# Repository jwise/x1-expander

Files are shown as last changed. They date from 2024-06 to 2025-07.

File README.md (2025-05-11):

# X1Plus Expander

This repository contains hardware development files for the X1Plus Expander,
[available-ish for purchase at Crowd
Supply](https://www.crowdsupply.com/accelerated-tech/x1plus-expander). 
Printer-side software to interface with these boards lives in the [X1Plus
repository](https://github.com/x1plus/x1plus).

If you have just purchased an Expander, you probably want to [read the
getting started guide](doc/getting-started.md)!

Each part has its own directory in this repository.  Part numbers always
begin with "X1P", are followed by three digits to identify the part, and
have a three-character revision number: a letter to identify
form/fit/function-incompatible revisions, and two digits to identify
FFF-compatible revisions.  Put together, a part and revision number looks
like "X1P-002-C02", to identify the an X1Plus Expansion Board mainboard, the
third FFF-incompatible revision, and the second FFF-compatible revision of
the X1P-002-C family.

This repository contains the following parts.  (Descriptions below may not
be representative of marketing names.)

 * [X1P-001](x1p-001/): wiring harness to connect X1P-002 to the printer
 * [X1P-002](x1p-002/): X1Plus Expander mainboard
 * [X1P-003](x1p-003/): manufacturing test harness for X1P-002
 * [X1P-004](x1p-004/): LED strip 3.3V->5V level shifter plugin
 * [X1P-005](x1p-005/): Andon board plugin
 * [X1P-006](x1p-006/): 2.5mm camera shutter release plugin
 * X1P-100 is a part number reserved for a bundle assembly of X1P-001,
   X1P-002, and X1P-800.
 * [X1P-800](x1p-800/): plastics for X1P-002

Ideally, each known version of each of these parts has its own git tag and
GitHub release with manufacturing data.  (Ideally.)

Also in this repository:

 * [utils/](utils/): software useful in manufacturing or bringup of X1P-*
   hardware
 * [doc/](doc/): documentation associated with X1P-* hardware
 * [fw/](fw/): firmware for the RP2040 on X1P-002-C series boards

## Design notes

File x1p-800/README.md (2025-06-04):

These plastics go with X1P-002-Bxx and X1P-002-Cxx boards.  See [assembly
documentation](../doc/assembly.md) for suggested assembly instructions.

See [OnShape
source](https://cad.onshape.com/documents/978d60c454bcccf39dac29ae/w/00e32d7fbc9730699d7762b9/e/21185136b3366b7afc3fb981)
to edit.

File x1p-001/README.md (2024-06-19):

To build: `wireviz harness.yaml -o X1P-001`

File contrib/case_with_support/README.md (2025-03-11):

This directory contains an alternative case designed by @liftbag (originally
shown
[here](https://github.com/X1Plus/X1Plus/discussions/445#discussioncomment-12460478)). 

This case offers nicer ergonomics and a more secure way to mount it, in
exchange for the need to print it with supports.  It hasn't been tested with
a real PCBA yet, but if you're willing to print with supports, I encourage
you to give it a try!

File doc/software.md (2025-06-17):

# Getting started with X1Plus Expander

This assumes that you have already [assembled the hardware](assembly.md).

## Installing a firmware

You will need to install an X1Plus firmware build that supports X1Plus
Expander.  Versions 3.0 and higher support the X1Plus Expander; if you're
currently running version 2.0 or higher, you can [use the built-in
over-the-air update
mechanism](https://github.com/X1Plus/X1Plus/wiki/User-Manual#over-the-air-updates-version-20-and-up). 
From earlier versions, please follow the "manual upgrade" steps [in the user
manual](https://github.com/X1Plus/X1Plus/wiki/User-Manual#manual-upgrades).

If you are running a firmware version that supports X1Plus Expander, you
should see "Expansion" appear in the "Hardware" tab, and if X1Plus Expander
is connected correctly and functioning properly, you should also see a
serial number appear underneath it.  You should also see "Wired Network"
appear in the "Network" tab if X1Plus Expander is connected and functioning.

## Connecting hardware to X1Plus Expander

X1Plus Expander port (the rectangular connectors on the top) are identified
by letters.  "B01" revisions of X1Plus Expander have only two functioning
ports -- the port on the left of X1Plus Expander (next to the I2C connector)
is "port B", and the connector two over from that is "port A".  (The port on
the right, and the port between port A and port B, are not usable in X1Plus
Expander B01; X1Plus Expander B01 hardware labels the usable ports in
silkscreen as "AD" and "BD".  All four ports will be usable in X1Plus
Expander revision C.) The leftmost port (port B, on revision B01) is always
shared with the STEMMA I2C connector.

It is better to power the printer off before connecting or disconnecting
add-on modules to the X1Plus Expander ports, but I can't stop you if you
really want to try it, and chances are good that you will probably get away
with it most of the time.

Add-on modules are not keyed right now.  Make sure that they are centered in
the port, and make sure that they face forward (i.e., that the arrow on the
add-on module matches up with the arrow on the port).

You can also connect other hardware to X1Plus Expander, using any standard
0.1" Dupont-style connector.  Doing so is outside of the scope of this
document, but if you get a hankering to do it, let me know what you are
trying to do and I will try to think up how you would do it, and document
it.

## Configuring X1Plus Expander

Currently, X1Plus Expander is primarily configured through the command line,
using the `x1plus settings` mechanism; a GUI to configure the ports is in
progress.  You can list all of X1Plus's settings with the `x1plus settings
get` command; conversely, you can also change settings with `x1plus settings
set`.  (You can run `x1plus settings set --help` to see exactly how it is
used.)

The settings keys for X1Plus Expander ports are `expansion.port_a` and
`expansion.port_b`, and should contain JSON objects that describe what is
connected to a port.  The exact format for these JSON objects is slightly in
flux, so for now, I'll provide recipes for setting up each supplied add-on
module:

### X1P-004 LED-strip level shifter module

Configure a port to drive an LED strip with:

```
# x1plus settings set expansion.port_x --json '{"ledstrip": {"leds": 10}}'
```

where "port_x" is correct for the port that you have plugged the X1P-004
into, and "10" has been changed to the correct number of LEDs in your LED
strip that you'd like to light up.  If you'd like to control which
animations are visible on your LED strip:

```
# x1plus settings set expansion.port_x --json '{"ledstrip": {"leds": 10, "animations": [{"running": {"brightness": 0.05}}, {"finish": {"brightness": 0.1}}]}}'
```

Available animations are `rainbow`, `paused`, `failed`, `running`, and
`finish`.  All animations take an optional `brightness` parameter (scaled
from 0 to 1); `failed` and `finish` also take an optional `timeout`
parameter (in seconds) to describe how long they should remain, before
returning to either a rainbow or a blank animation.

If you find it easier, you can also configure a port using a JSON or YAML
file, rather than having to input an entire JSON string in a command line
parameter.  For instance, you can do:

```
# cat > ledstrip.yaml <<EOF
ledstrip:
  animations:
  - running:
      brightness: 0.05
  - finish:
      brightness: 0.1
  leds: 10
EOF
# x1plus settings set expansion.port_x --file ledstrip.yaml --yaml
```

You may find this more convenient to experiment with.

TODO: document where to connect what for LED strips, and how to use an external power supply, if it is not obvious

### X1P-005 Andon module

An Andon module is just an LED strip module with 25 fixed LEDs on it, a
buzzer, and two buttons that serve as inputs.  This introduces the `gpio`
parameter to the `ledstrip` type of module.  I recommend a configuration for
X1P-005 that looks about as follows:

```
# x1plus settings set expansion.port_x --json '{"ledstrip": {"leds": 25, "gpios": [{"pin": 3, "function": "buzzer", "default": 0}, {"pin": 5, "default": 1}, {"pin": 6, "function": "button", "inverted": true}, {"pin": 7, "function": "button", "inverted": true}]}}'
```

You may also consider a YAML equivalent, if you wish to play with the
animations.  For instance, consider:

```
# cat > andon.yaml <<EOF
ledstrip:
  animations:
  - running:
      brightness: 0.05
  - rainbow:
      brightness: 0.1
  gpios:
  - pin: 3
    function: buzzer
    default: 0
  - pin: 5
    default: 1
  - pin: 6
    function: button
    inverted: true
  - pin: 7
    function: button
    inverted: true
  leds: 25
```

The Andon module will, by default, light up like any other LED strip.  To
use the buzzer or buttons, see the "Using X1Plus Actions" section, below.

### X1P-006 Shutter release module

A shutter release module is a GPIO module that has two outputs. 
Conveniently, the `ledstrip` driver can be used to drive GPIOs (the shutter
release module does not have anything connected to the LED output pin).  You
can configure a shutter release module as follows:

```
# x1plus settings set expansion.port_x --json '{"ledstrip": {"leds": 0, "gpios": [ { "pin": 3, "function": "shutter", "default": 0 }, { "pin": 5, "function": "shutter", "default": 0 } ] } }'
```

### Using I2C sensors

TODO: document `i2c` driver

## Using X1Plus Actions

X1Plus Actions is a new mechanism to trigger behavior from inside X1Plus. 
Actions are a commonized way to trigger tasks from the command line, from
G-code, or in response to various system events (including button presses). 
Actions are either a JSON dictionary specifying an Action, or a list of
Actions.  For instance, the following is a valid Action:

```json
{
  "gpio": {
    "action": "pulse",
    "duration": 0.5,
    "gpio": {
      "function": "buzzer"
    }
  }
}
```

This Action calls the "gpio" action type, and provides it with three
parameters -- a subaction ("pulse", which turns a GPIO on for `duration`
time, and then turns it back off), a duration, and a GPIO specification.  In
this case, the GPIO specification causes the `pulse` to match all GPIOs on
the system that have a `function` of `buzzer`.

The following is also a valid Action:

```json
{ "delay": 0.5 }
```

This Action simply waits for 0.5 seconds before proceeding.  If you executed
this Action on its own, you would see nothing, but if you created a list of
Actions with this as a part of it, you would see a delay happen in between
beeps:

```json
[
  {"gpio": {"action": "pulse", "duration": 0.5, "gpio": {"function": "buzzer"}}},
  {"delay": 0.5},
  {"gpio": {"action": "pulse", "duration": 0.5, "gpio": {"function": "buzzer"}}}
]
```

Another useful type of action is to submit G-code to the MC.  For instance,
you might consider:

```json
{"gcode": "G91\nG0 Z-7.5"}
```

which puts the printer into relative mode, and then jogs the Z axis.

### Testing Actions from the command line

You can use the `x1plus action` command to submit an Action from the command
line.  Like `settings`, it allows you to use JSON on the command line, JSON
from a file, or YAML from a file.  For instance, to make a pleasing
bee-beep! sound from any buzzers that you have connected, consider:

```
# x1plus action --json '[{"gpio": {"action": "pulse", "duration": 0.08, "gpio": {"function": "buzzer"}}}, {"delay": 0.08}, {"gpio": {"action": "pulse", "duration": 0.05, "gpio": {"function": "buzzer"}}}]'
```

You may find it more friendly to edit your actions in JSON on disk.  For
instance, you might prefer:

```
# cat > beep.json <<EOF
[
    {
        "gpio": {
            "action": "pulse",
            "duration": 0.08,
            "gpio": {
                "function": "buzzer"
            }
        }
    },
    {
        "delay": 0.08
    },
    {
        "gpio": {
            "action": "pulse",
            "duration": 0.05,
            "gpio": {
                "function": "buzzer"
            }
        }
    }
]
EOF
# x1plus action --json --file beep.json
```

Or you may even prefer to edit your actions in YAML, since after all, JSON
is a rather unpleasant language to write by hand.  For this, you might
prefer:

```
# cat > beep.yaml <<EOF
- gpio:
    action: pulse
    duration: 0.08
    gpio: 
      function: buzzer
- delay: 0.08
- gpio:
    action: pulse
    duration: 0.05
    gpio: 
      function: buzzer
EOF
# x1plus action --yaml --file beep.yaml
```

If you have an X1P-007 shutter release connected, you might otherwise prefer
to trigger a shutter to test it.  Connect your camera, and try:

```
# x1plus action --json '{"gpio": {"action": "pulse", "duration": 0.15, "gpio": {"function": "shutter"}}}'
```

You can match on other properties, as well.  For instance, if you'd like to
trigger only one of the two connected cameras, and you care about which port
it's on:

```
# x1plus action --json '{"gpio": {"action": "pulse", "duration": 0.15, "gpio": {"function": "shutter", "pin": 3, "port": "b"}}}'
```

This matches on only things that have a function of "shutter", *and* are on
pin 3, *and* are plugged into port B.

### Embedding Actions in G-code

*This section describes in detail how G-code embedded Actions work, but if
you would just like some recipes that you can paste into the G-code window
in your slicer, see below.*

You can run X1Plus Actions from inside G-code.  The general concept is that
you define an action number using a specially-formatted `;x1plus define`
comment, and then use the G-code command `M976 S99 Pn` to trigger it.  For
instance, you can trigger the buzzer with a G-code command sequence as
follows:

```
G0 X... Y...
;x1plus define 5 {"gpio": {"action": "pulse", "duration": 0.2, "gpio": {"function": "buzzer"}}}
M976 S99 P5
G0 X... Y...
```

(Note that an `;x1plus define` must always come before its respective `M976
S99`, and you should not redefine an action number to a new value later in a
print -- however, it is safe to redefine an action to the same value as it had
previously, however.)

#### Using compiled Actions in G-code

Unfortunately, most slicers will not accept commands with `{curly braces}`
-- they seem to interpret these as variable substitution.  X1Plus supports
an alternate "compiled" syntax, which does not include curly braces; you can
use the `x1plus convert` command to convert JSON or YAML into the "compiled"
form.  For instance, you can convert the above action as:

```
# x1plus convert '{"gpio": {"action": "pulse", "duration": 0.2, "gpio": {"function": "buzzer"}}}'
eNqrVkovyMxXslKoVkpMLsnMzwMylQpKc4pTlXQUlFJKixKhggZ6RkABuOK00jy48qTSqqrUIqXa2loAyekZIg==
```

Or, equivalently:

```
# cat > beep.yaml <<EOF
gpio:
  action: pulse
  duration: 0.2
  gpio:
    function: buzzer
EOF
# x1plus convert --file beep.yaml
eNqrVkovyMxXslKoVkpMLsnMzwMylQpKc4pTlXQUlFJKixKhggZ6RkABuOK00jy48qTSqqrUIqXa2loAyekZIg==
```

You can use this "compiled" string the same way as you would a JSON string. 
For instance, to beep on each layer change, you could insert the following
into your layer change G-code in your slicer:

```
;x1plus define 1 eNqrVkovyMxXslKoVkpMLsnMzwMylQpKc4pTlXQUlFJKixKhggZ6RkABuOK00jy48qTSqqrUIqXa2loAyekZIg==
M976 S99 P1
```

You can also use `x1plus convert` to produce readable JSON or YAML from
compiled Actions:

```
# x1plus convert --to=json eNqrVkovyMxXslKoVkpMLsnMzwMylQpKc4pTlXQUlFJKixKhggZ6RkABuOK00jy48qTSqqrUIqXa2loAyekZIg==
{
    "gpio": {
        "action": "pulse",
        "duration": 0.2,
        "gpio": {
            "function": "buzzer"
        }
    }
}
```

#### Pausing G-code until an Action completes

By default, `M976 S99`-triggered Actions will run in parallel with G-code --
i.e., movement commands will continue to run while the Action runs.  For
certain actions -- like time lapses, or waiting for external GPIOs, you may
wish to have G-code wait until an Action completes.  You can do this using
the `M400 W1` and `M400 W0` G-code commands.  `M400 W1` will cause G-code to
stop executing until an Action sends a `M400 G0` G-code.  For example,
consider the following G-code sequence:

```
G0 X100 Y175  ; move the toolhead
G0 X100 Y100
M400          ; wait for all toolhead motion to complete
; Define an action that pulses the shutter, waits, and then resumes G-code execution.
;x1plus define 1 [{"gpio": {"action": "pulse", "duration": 0.5, "gpio": { "function": "shutter" }}}, {"delay": 1.0}, {"gcode": "M400 W0"}]
M976 S99 P1   ; trigger the action
M400 W1       ; pause until the M400 W0 is sent
G0 X175 Y100  ; move the toolhead
G0 X175 Y175
```

This sequence, as described, causes the printer to stop moving until the
Action finishes and the camera has taken its photo (as one might hope for a
potentially long exposure required for good depth of field!).

#### Recipe: triggering a shutter on layer change

The above G-code is appropriate for triggering a shutter, but is not
suitable for embedding in a slicer configuration -- the Action is not
encoded in compiled format.  To use an Action to trigger a shutter, modify
the Machine G-code in your slicer, and add the following to the Layer change
G-code:

```
M400
; pulse shutter for 0.5 seconds, and then wait 1.0 seconds before proceeding
;x1plus define 100 eNqLrlZKL8jMV7JSqFZKTC7JzM8DMpUKSnOKU5V0FJRSSosSoYIGeqZAAbjitNI8uPLijNKSktQipdraWh2gVEpqTmIlUNxQzwDMT0/OT0kFqfM1MTBQCDdQqo0FAMvxJHo=
M976 S99 P100
M400 W1
```

Place these commands immediately underneath the `M971 S11 C10 O0` command. 
(This command will appear twice: one for "without wipe tower", and one for
"with wipe tower".  Insert the commands underneath both.

To start off with, I suggest the following (he says, as a checklist for
himself...):

* Make sure your camera has auto white balance turned off; that your camera
  is set for a fixed ISO, shutter speed, and aperture; and that your camera
  will not attempt to autofocus.
* Home the bed before printing, and then move the toolhead out of the way,
  move the bed up, and focus on or slightly beyond the bed.
* If using a macro / zoom lens, you probably want to stop the aperture down
  more than you think to achieve a usably wide depth of field.
* You probably do not want to shoot 800 RAW photos, so if you normally shoot
  RAW, remember to set the camera to JPEG only...
* Unsurprisingly, smaller layer heights result in "smoother" time lapses.
* The object will grow taller than you think.  If you are zoomed way in,
  consider putting the build area for your part in the very top of the
  frame.
* Don't be afraid to take long exposures!
* If it's an option on your camera, remember to connect it to external
  power (or use a battery emulator, if you're on a camera that has the
  shutter release occupy the same plug as a power adapter).
* Make sure your camera has auto-sleep turned off, if applicable.
* Give your test image one last pixel-peep to make sure you aren't about to
  take a 12 hour time lapse of crap...

#### Recipe: sounding the buzzer

You may also wish to sound the buzzer, either at the end of a print, or upon
a certain layer being reached.  You can paste the following G-code into a
slicer to sound the buzzer for half a second:

```
; sound buzzer for 0.5 seconds
;x1plus define 101 eNqrVkovyMxXslKoVkpMLsnMzwMylQpKc4pTlXQUlFJKixKhggZ6pkABuOK00jy48qTSqqrUIqXa2loAylIZJQ==
M976 S99 P101
```

### Triggering Actions from buttons

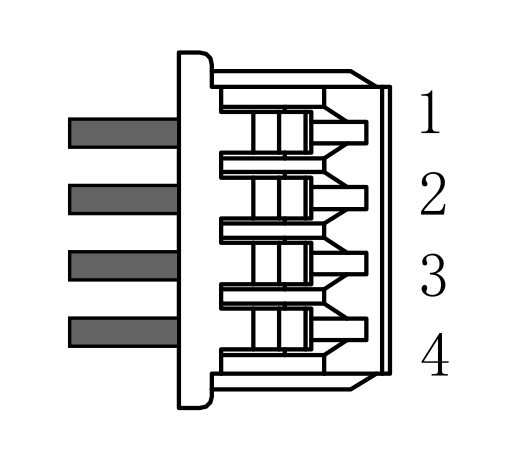
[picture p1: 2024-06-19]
x1p-001/dll_mh1_25_4y.png

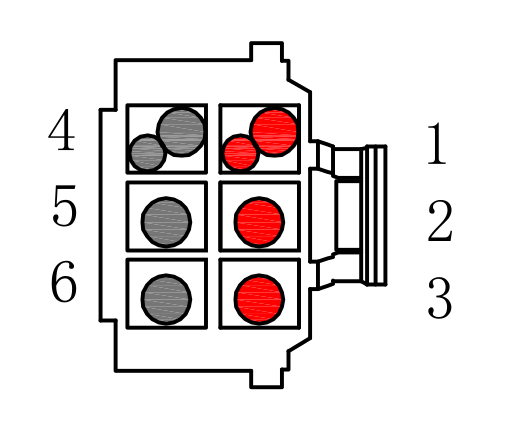
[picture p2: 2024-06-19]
x1p-001/hc_phb_2_3_y.png

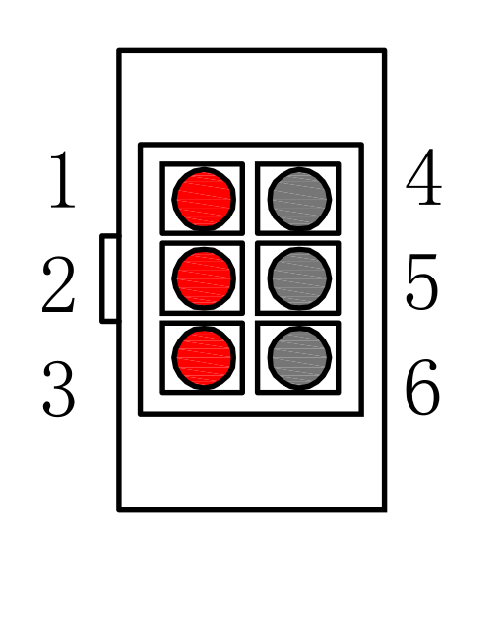
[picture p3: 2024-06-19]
x1p-001/hc_phb_2_3_ey.png

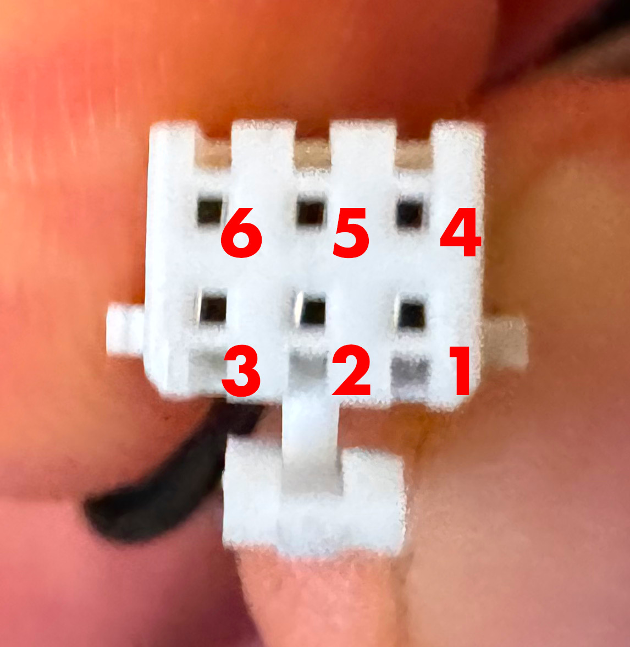
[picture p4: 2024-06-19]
x1p-001/hc_phb_2_3_y.jpg

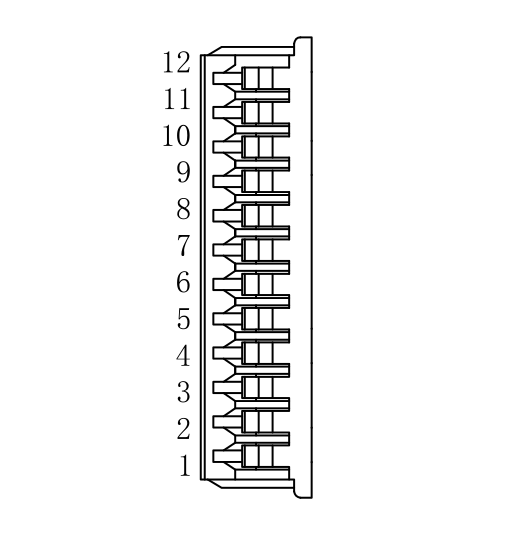
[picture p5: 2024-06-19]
x1p-001/dll_mh1_25_12y.png

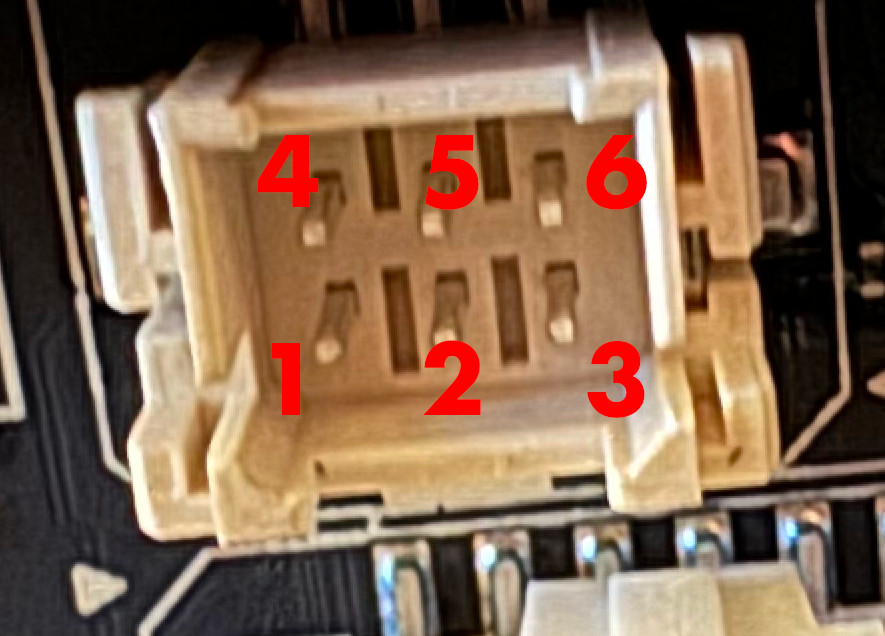
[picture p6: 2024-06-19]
x1p-001/hc_phb_2_3_ey.jpg

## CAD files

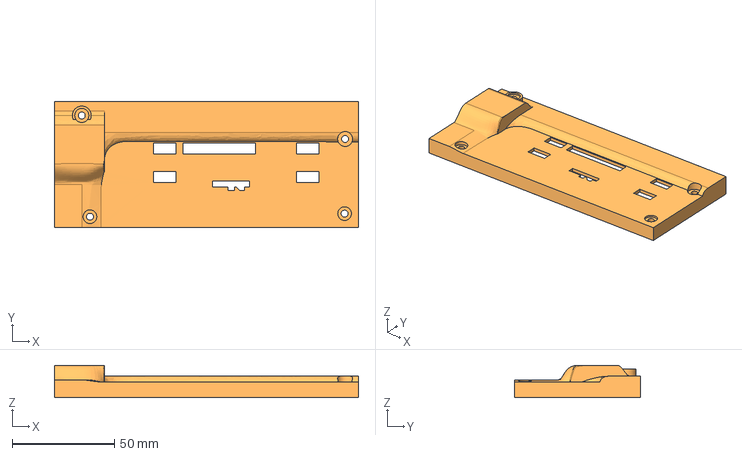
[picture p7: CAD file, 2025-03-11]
contrib/case_with_support/upper_shell.step
148.6 x 61.7 x 15.9 mm

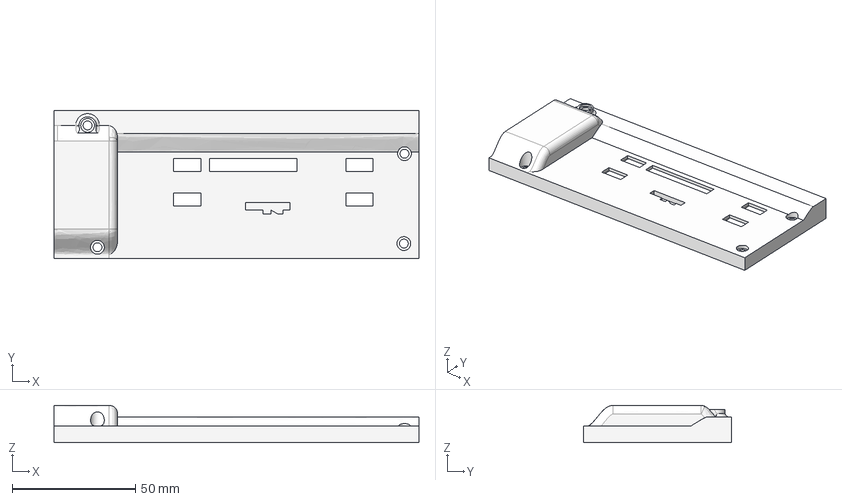
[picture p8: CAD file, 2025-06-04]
x1p-800/FDM/X1P-800 Upper shell.step
148.3 x 60.3 x 15.1 mm

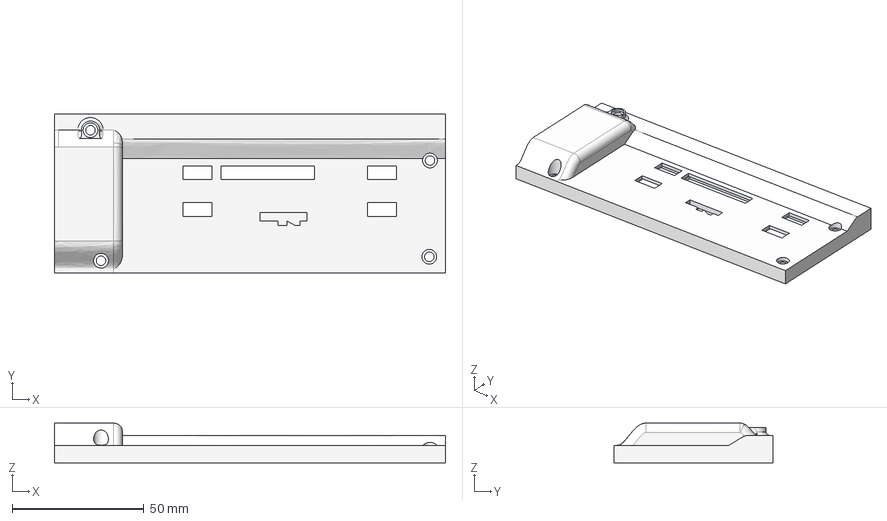
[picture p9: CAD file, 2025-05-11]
x1p-800/SLS/X1P-800-A02-B.step
148.3 x 60.3 x 15.1 mm

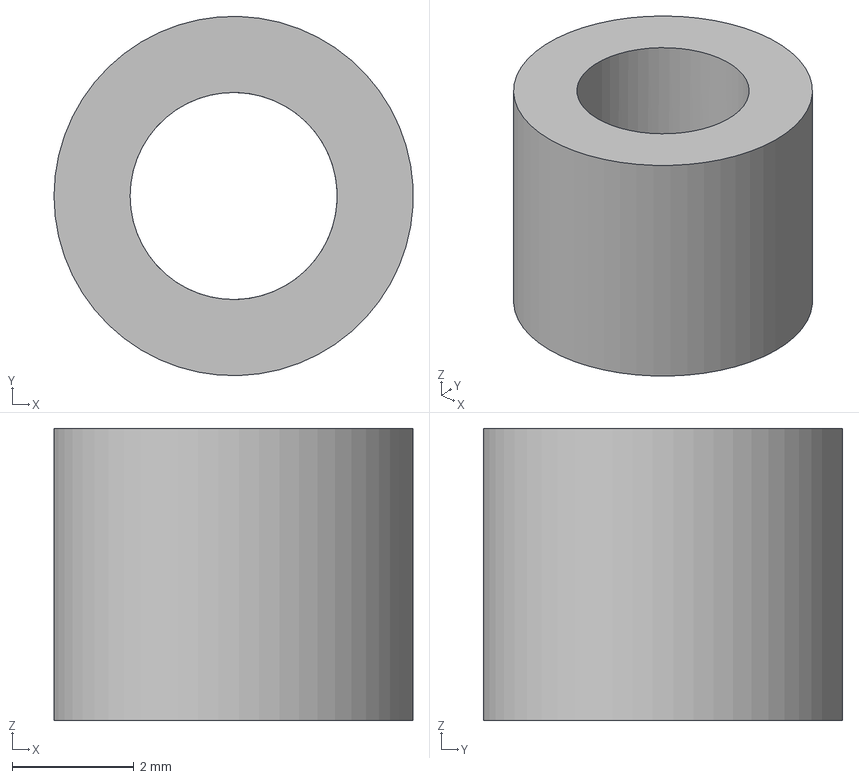
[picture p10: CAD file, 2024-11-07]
x1p-800/X1P-800 Standoff LL.step
5.90 x 5.90 x 4.80 mm

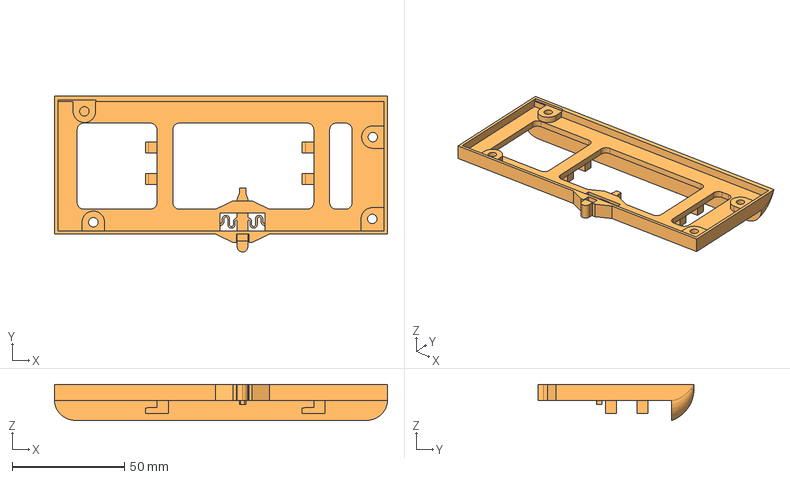
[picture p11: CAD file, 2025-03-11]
contrib/case_with_support/lower_shell.step
148.6 x 69.7 x 16.1 mm

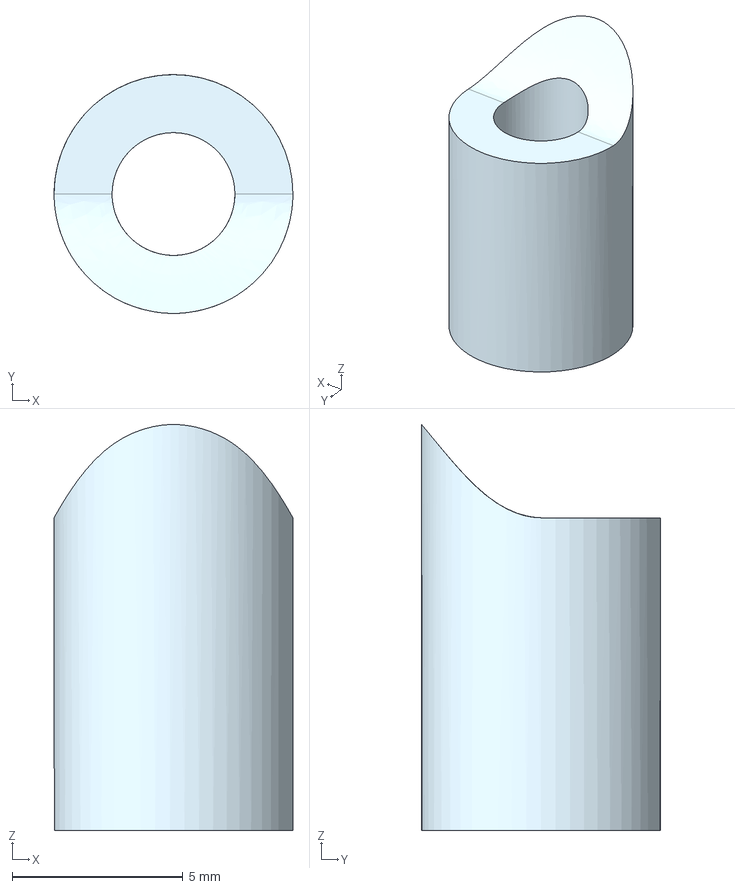
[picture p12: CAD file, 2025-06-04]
x1p-800/FDM/X1P-800 Tall standoff.step
7.00 x 7.00 x 11.9 mm

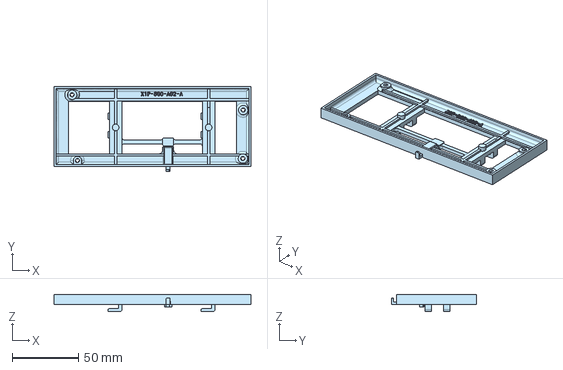
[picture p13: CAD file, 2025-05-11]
x1p-800/SLS/X1P-800-A02-A.step
148.3 x 63.8 x 13.0 mm

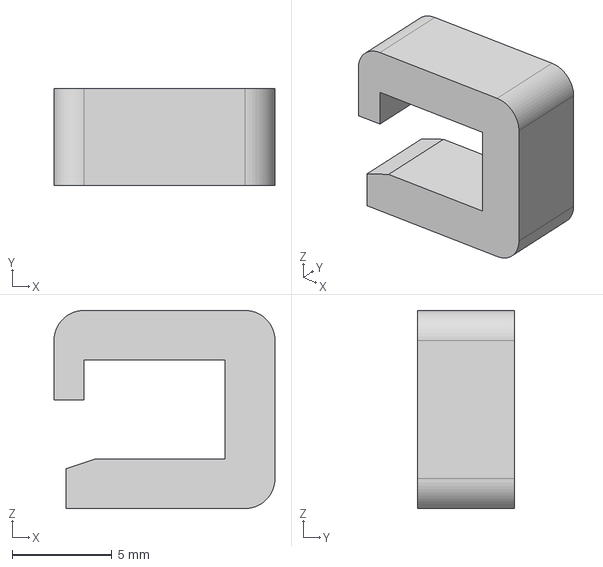
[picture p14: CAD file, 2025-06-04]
x1p-800/FDM/X1P-800 Clip.step
11.1 x 4.85 x 9.95 mm

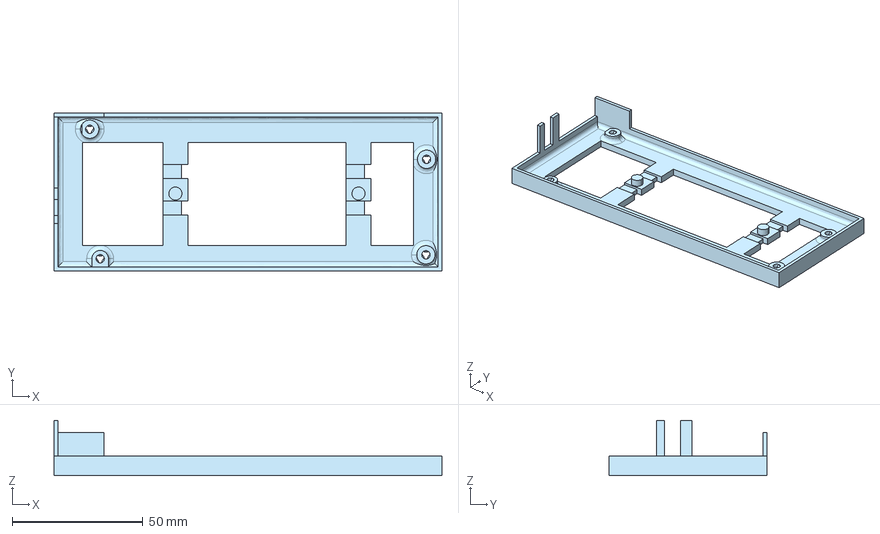
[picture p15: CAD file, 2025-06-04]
x1p-800/FDM/X1P-800 Lower shell.step
148.3 x 60.3 x 21.2 mm

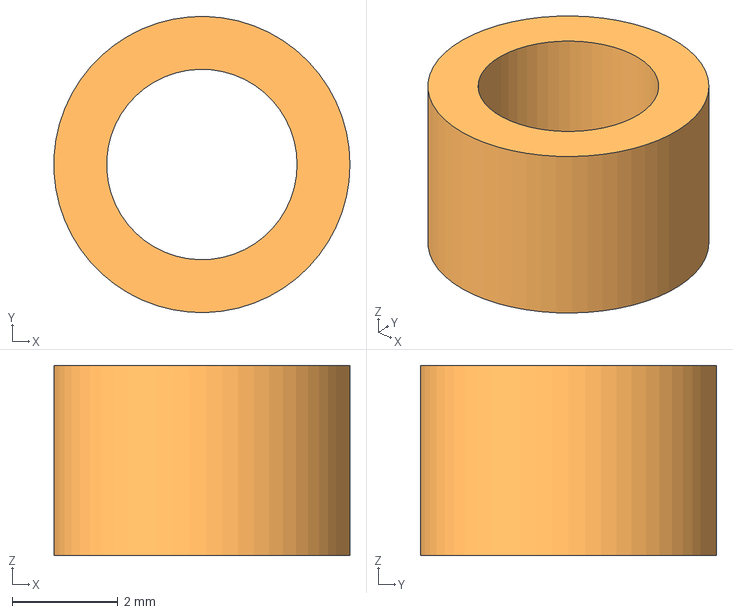
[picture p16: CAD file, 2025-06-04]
x1p-800/FDM/X1P-800 Short standoff.step
5.60 x 5.60 x 3.60 mm

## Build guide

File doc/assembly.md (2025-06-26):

# Assembly instructions for X1Plus Expander

Below is a textual description of how to install Expander into your printer. 
You should read it in its entirety before you install Expander.  But, since
I know that none of you are going to, I also recorded a video, and here it
is:

X1Plus Expander Installation Guide (https://www.youtube.com/watch?v=XNPRE-L4nhQ)

([https://www.youtube.com/watch?v=XNPRE-L4nhQ](https://www.youtube.com/watch?v=XNPRE-L4nhQ))

But **you should really read the words too before you try installing
Expander**!

## Assembling Expander with a SLS case

The easiest way to physically assemble X1Plus Expander, of course, is to
just buy a [case / mounting bracket from Crowd
Supply](https://www.crowdsupply.com/accelerated-tech/x1plus-expander)!  They're lovely SLS
nylon parts that are mostly dimensionally accurate, and even include a
locking tab that mates with the front of the printer.  The SLS case is
designed to work with the screw bundle that comes with the X1Plus Expander
package.

## Assembling Expander with an FDM case

If you did not buy an Expander from Crowd Supply, you can print a set of
plastics for Expander yourself.  To do this, download and print [the X1P-800](../x1p-800/FDM)
parts.  Some hints for how to print it:

  * You will need four copies of the clips, and three copies of the short standoff.  (Since the clips and standoffs are small, you might want to print some extras while you're at it.)

  * The lower shell can be more reliable to drive screws into if printed from PETG; the clips are also less prone to creep if printed from PETG. 

  * The upper shell is best printed standing on end.  It's OK to print it out of PLA if you want the matte cosmetic look rather than the gloss PETG look.

For reference, one print orientation that works for me is shown below.

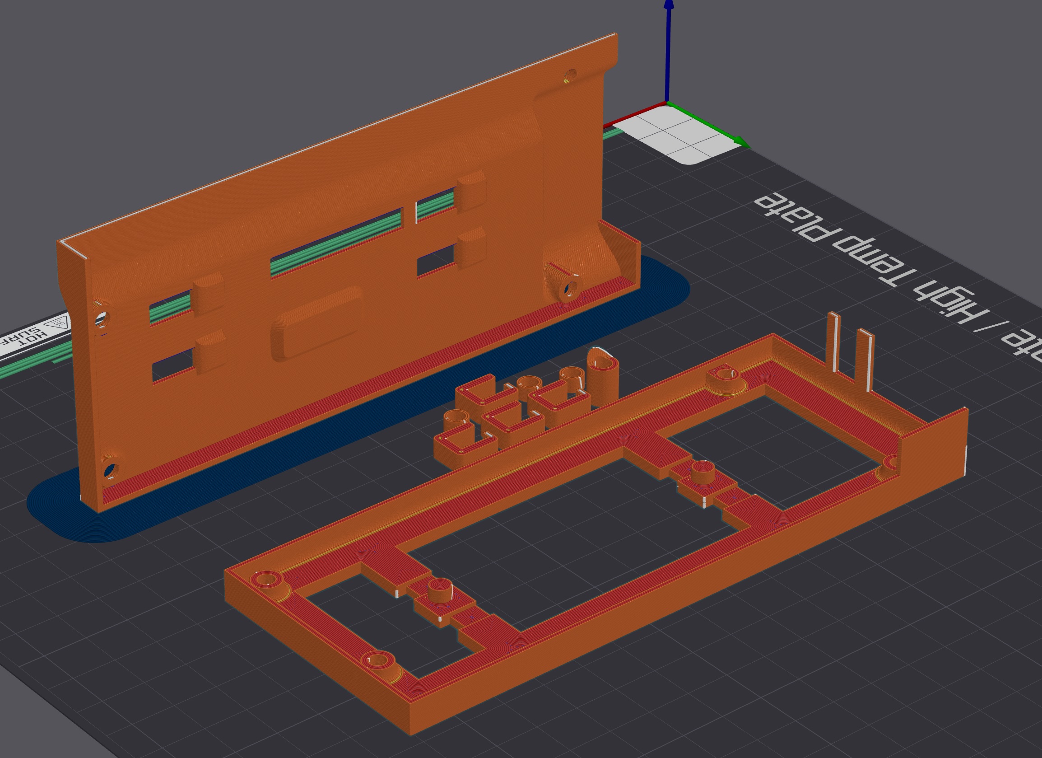
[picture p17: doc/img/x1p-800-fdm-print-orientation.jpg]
An example print orientation of X1P-800 parts, with the lower shell standing on end.


Once printed, you will want to pre-assemble the case before attaching it to your printer:

  * Take the upper shell and the standoffs, and run the included M3 screws through them to ensure that they clear (it should be a clearance fit).

  * One of the standoffs is differently shaped; it mates with the curved face of the upper shell.  Line up all four standoffs in place on the upper shell, using the M3 screws to align them.  Use a dab of cyanoacrylate to hold them in place on the top case, so they don't run away when you try to assemble it.

  * Take the bottom case and attach the clips; they should snap in satisfyingly.  The open end of the clips should face left, since that's how it'll slide into the printer.  Once you're sure they attach correctly, use a dab of cyanoacrylate to attach them to the bottom case.  (This isn't entirely necessary, since the clips do have small hooks, but it can save you from some annoyance later when you're trying to juggle parts to assemble.)

  * Let the cyanoacrylate cure overnight to avoid frosting your board and/or printer.  If you prefer, instead of cyanoacrylate, you can use some heat to melt the plastic to bond the parts together -- the adhesive is only there to keep parts together during assembly.

See the exploded views before for more detail.

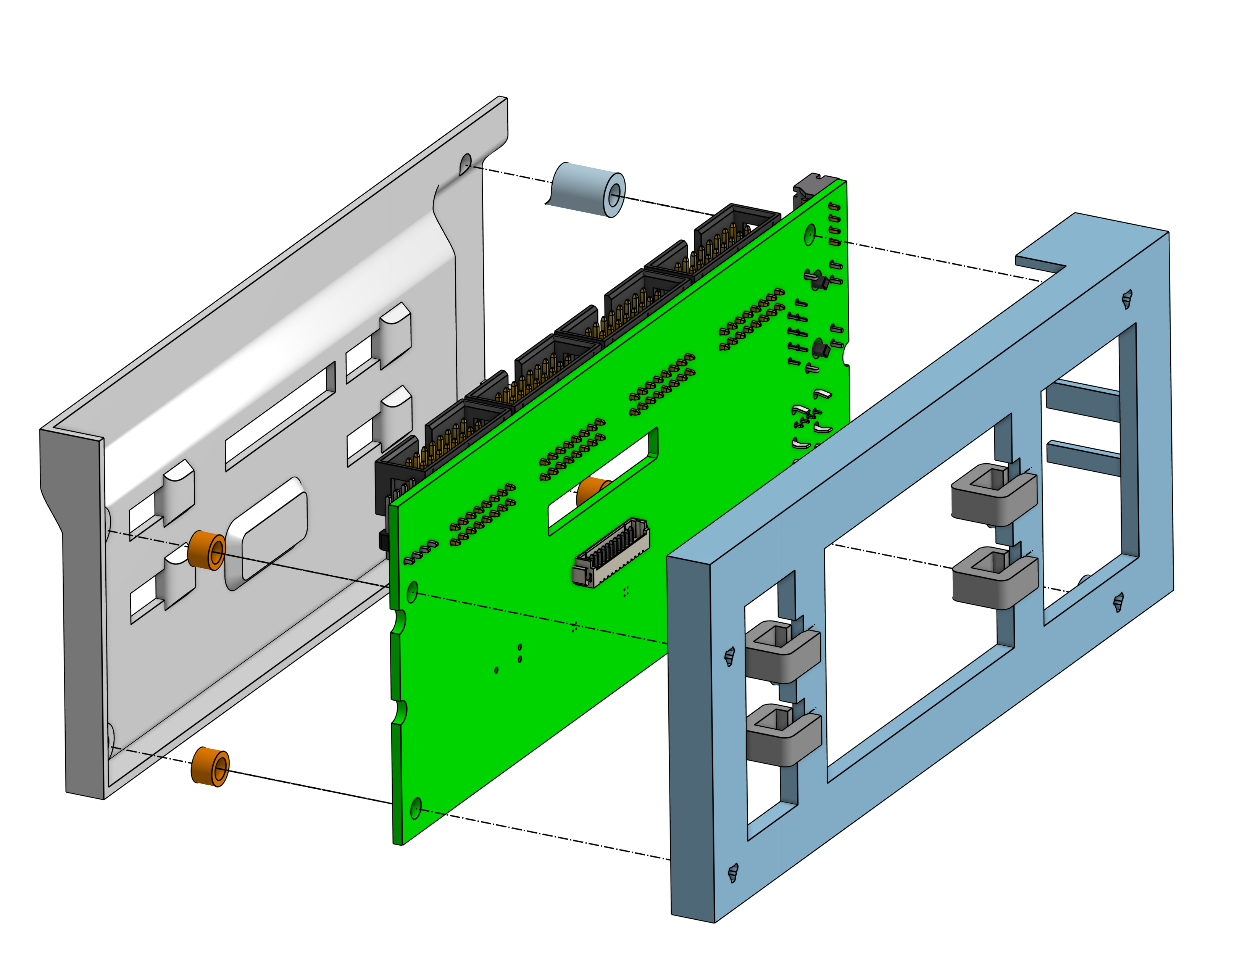
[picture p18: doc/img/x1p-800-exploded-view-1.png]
A full assembly explosion of X1P-800.


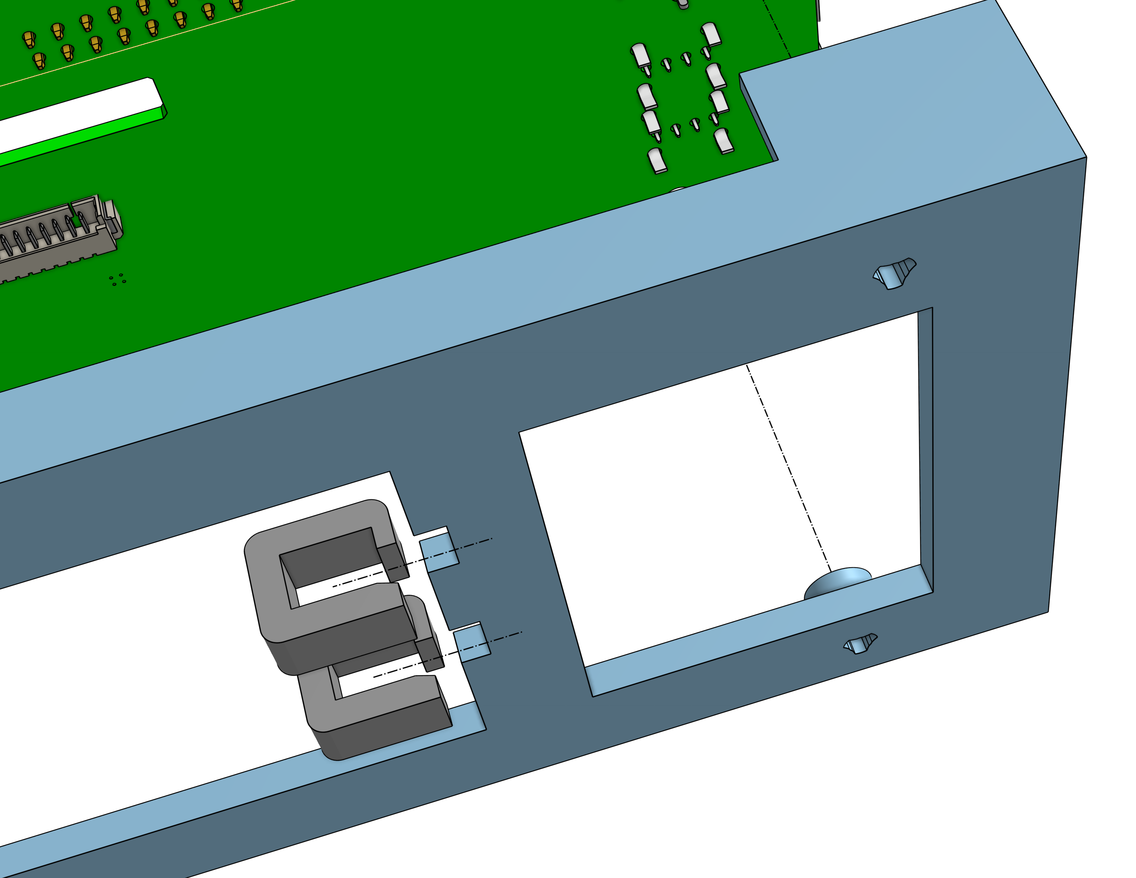
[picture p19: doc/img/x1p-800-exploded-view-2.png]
Detail of clip installation direction.


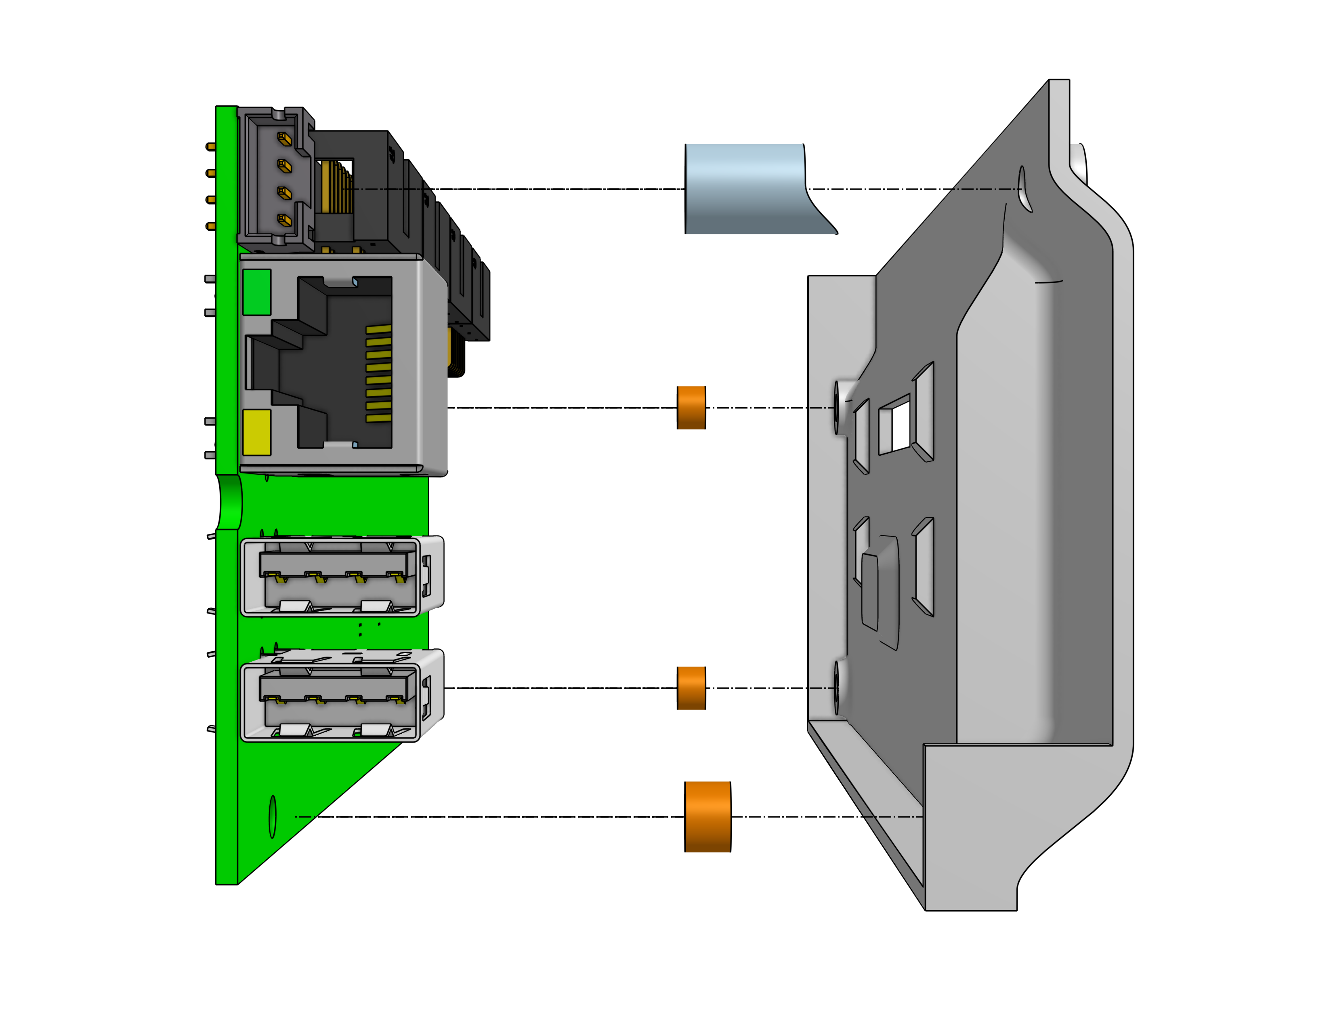
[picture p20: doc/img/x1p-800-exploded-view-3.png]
Detail of standoffs.


## Installing Expander into your printer

For those of you that bought an Expander case, the plastics that you
received are designed to work with the M3 screws that you received with
Expander, and you should not need to do any pre-assembly.

Once you have an Expander case ready to go, you're ready to install Expander into your printer!  To install it:

  * Power down and unplug your printer, of course.

  * Remove the LCD from your printer (remember that you have to press on the bottom of the hinge and slide right).  Disconnect the cable by pinching the sides.

  * Remove the AP board cover, and disconnect the power cable and camera cable from your AP board.  Connect the X1P-001 wiring harness to the AP board: the 4-pin cable labeled "CAM" plugs in where the camera previously connected, the 4-pin cable labeled "UART" plugs in to the other mating connector, and the harness's power cable plugs in where the power cable previously plugged in.

  * Plug the other mating connectors on the harness into the things that were previously connected: attach the camera to the X1P-001 wiring harness, and attach the power supply to the X1P-001 wiring harness.

  * Carefully route the wiring harness through the front of the printer, below the LCD cable.  Snap the AP board cover back in place.

  * Attach the lower shell to the front of the printer by pressing on the clips and sliding left.  If you have a SLS case, verify that the locking tab engaged.

  * Connect the wiring harness to the X1P-002 mainboard.  It is a tight fit: use your fingernails walking back and forth on either side of the cable until it is fully inserted.  It will only insert in one direction.

  * Feed the LCD cable through the hole in the X1P-002 mainboard, and the hole in the upper shell.

  * Line up the X1P-002 mainboard, the lower shell, and the upper shell.  Use the included M3 screws to attach it.  Tighten them incrementally in a circle.  Be gentle with the screws -- you are screwing a relatively small thread into plastic self-tapping holes, and it is easy to strip the plastic if you "go bananas" with the screw torque!

  * Attach the LCD cable to the display.  Attach the display to the front of the upper shell; it should make a satisfying "Snap!" when it locks into place.

  * Now is a good time to plug in any modules that you may have bought.  **Do not install or remove plug-in modules while the printer is powered on!*

  * Power up your printer.  (Glowing red LEDs on the mainboard are expected, and indicate correct power supply operation.)  Ensure that the printer's built in camera still works, then proceed to installing software!

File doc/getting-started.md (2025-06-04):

# Getting started with X1Plus Expander

Hi!  Thank you for buying [X1Plus
Expander](https://www.crowdsupply.com/accelerated-tech/x1plus-expander)!  It
has been quite a fun project to make this for you, and I'm glad that it's in
your hands.  This document will describe how to install Expander into your
printer, and will provide you with information on how to operate it.

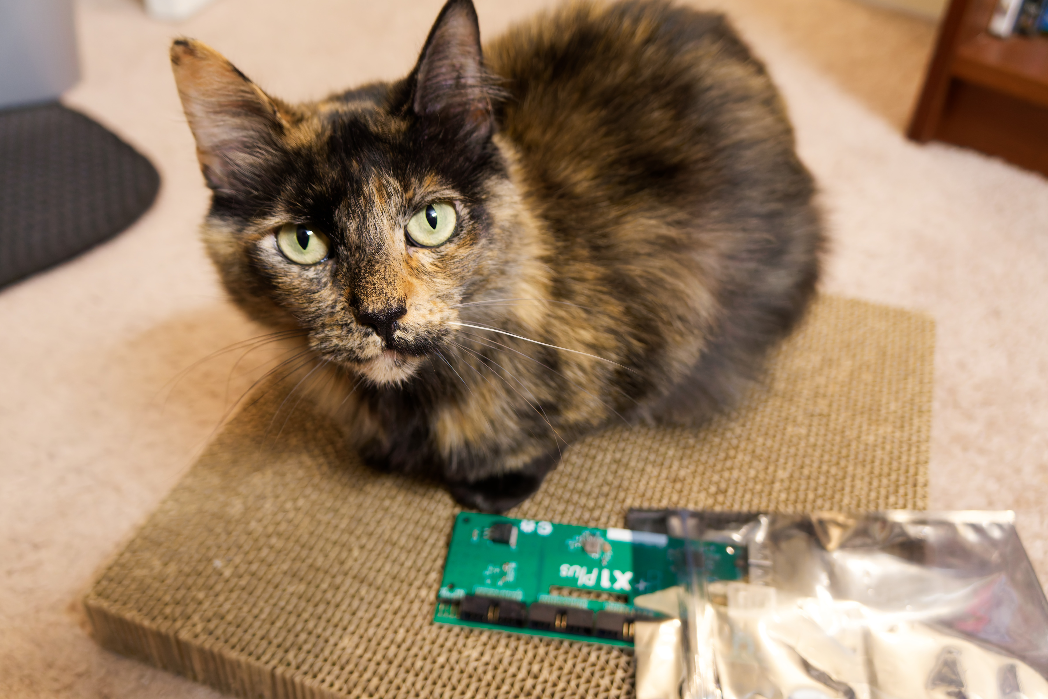
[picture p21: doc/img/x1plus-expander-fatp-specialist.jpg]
Peanut looks at an early Expander prototype.


## Getting Expander

X1Plus Expander is the hardware companion to the X1Plus open-source custom
firmware distribution for Bambu Lab’s X1 3D printers.  It extends your
printer’s functionality with an Ethernet port, two USB ports, a
STEMMA-compatible I²C connector, and four interchangeable GPIO headers for
expansion modules.

If you've come to this page and you *don't* own an X1Plus Expander, then you
should [buy one from Crowd
Supply](https://www.crowdsupply.com/accelerated-tech/x1plus-expander)! 

## Unpacking Expander

Your X1Plus Expander should have come in a brightly colored box labeled
"X1P-100".  Inside the box, there should be:

* One X1P-002 Expander mainboard.
* One X1P-001 wiring harness.
* A small baggie with three M3x12 screws, and one M3x18 screw.
* A ping-pong ball with a picture of Peanut, the cat, on it.
* A sheet with Instructions for Safe Use (or Sicherheitshinweise, if you
  prefer to read them in German).

Make sure that you have everything, and take a moment to read the
Instructions for Safe Use, and ensure that you understand them.  (You can
also read them [right here](instructions-for-safe-use.md), if you prefer.)

If you purchased other accessories, they will be packaged and labeled separately.

## Getting help with Expander

X1Plus Expander is not affiliated with, supported by, or endorsed by Bambu
Lab.  Accelerated Tech and X1Plus do not have any relationship with Bambu
Lab, and, in fact, they mostly just grudgingly put up with us.

That means that if something goes wrong with your printer, and you have
Expander installed, you have to remove it and uninstall X1Plus before you
can get support from Bambu Lab!

If you need help with Expander itself, you should first try the [Bambu
Unofficial Discord](https://discord.gg/4SfCufp6SB).  You can also send us an
e-mail through the [Crowd Supply contact
form](https://www.crowdsupply.com/accelerated-tech/x1plus-expander/ask-question).

## Installing Expander into your printer

Once you have unpacked X1Plus Expander, you'll need to assemble the hardware
and physically connect it to your printer.  [Read through the assembly guide
in its entirety](assembly.md), and after that, you can start connecting
wires to your printer.

Then, once you have Expander installed in your printer, you can [install the
appropriate software on your printer](software.md).  The software guide
[also discusses how to configure Expander](software.md).

## Other resources

[This repository](https://github.com/jwise/x1-expander) also contains the
full source code for the X1Plus Expander firmware, and CAD files if you
would like to make your own plug-in modules.  It also contains the
manufacturing software associated with the FATP process for Expander.  All
of the plastics designed for this project [were made with Onshape, and are
publicly available as
well](https://cad.onshape.com/documents/978d60c454bcccf39dac29ae/w/00e32d7fbc9730699d7762b9/e/c5ed48786c10ad210482490c).

Happy printing!

## Thanks to

Many people helped in the making of X1Plus Expander.  Here is a short list,
in no particular order, of people that I would like to credit.  I hope I did
not leave anyone out, but if I did, I hope also that you'll accept my
apologies...

* NixieBunny, who more than anything else, kept the idea of this
  project alive and made sure it happened.  He did some of the first
  schematics for Expander, and some of the early proto runs came out of his
  pocket; he reviewed many different versions of schematics and layouts,
  tested and reworked varying versions of the PCBs, and shipped them off to
  some of our early beta testers.  
* [Annie Ruygt](https://annieruygtillustration.com/) designed
  the unbelievable art for the X1P-100 box.  I gave her a vague idea of what
  I wanted, and she basically read my mind for the rest of it, and I'm so
  happy with what she came up with!
* DieterTheHorst, esden, and namibj, who helped with the German translation
  of the Instructions for Safe Use.
* The amazing team at Crowd Supply made it logistically possible for me to
  offer this kind of product to more people than just a handful of friends,
  and have graciously guided me through the process as a first-time creator.
* The "100% human created" icon on the box was designed by Thomas Knutsen. 
  [X1Plus Expander was created without the use of Generative Artificial
  Intelligence](https://no-ai-icon.com/statement/?url=https://github.com/jwise/x1-expander).
* Peanut was the executive supervisor for the X1Plus Expander project.

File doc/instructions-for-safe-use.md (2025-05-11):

# Instructions for Safe Use

* Expander is not designed for safety-critical applications, like closed
  loop control of a chamber heater.  Safety-critical applications must have
  failsafes independent of the Expander hardware.
* Modifying 3D printers with community-provided firmware carries inherent
  risk.  Modified or not, always supervise your printer when it is in
  operation.
* Do not draw more than 2A at 5V, or 1A at 3.3V, or a total of 10W, from
  Expander’s built in power supplies.  Limit current through each pin to the
  amount specified by each connector.
* Expander must be connected only to the power supply built into the X1
  Carbon.
* Expander should be covered by a non-conductive case, and must not be
  contacted by conductive items.
* The connection of unapproved devices to any receptacle may affect
  compliance or result in damage to the unit and invalidate the warranty.
* Do not expose Expander to water, moisture, or place it on a conductive
  surface while it is in operation.  Do not place it inside the printer’s
  print area, and keep it away from heat.
* Take care when handling to avoid mechanical or electrical damage to the
  printed circuit board and connectors.  Avoid handling Expander while it is
  powered.  Handle Expander only by the edges to minimize the risk of
  electrostatic discharge damage.
* All peripherals used with Expander should comply with relevant standards
  for the country of use and be marked accordingly to ensure that safety and
  performance requirements are met.  These articles include but are not
  limited to the add-on modules used in conjunction with Expander.

# Sicherheitshinweise

* Der X1Plus Expander ist nicht für sicherheitskritische Anwendungen
  vorgesehen.  Verwendungen wie der Betrieb einer Druckkammerheizung im
  geschlossenen Regelkreis setzen unabhängige Betriebssicherheitsmaßnahmen
  voraus.
* Für Veränderungen am Gerät durch herstellerfremde Hardware kann keine
  Haftung übernommen werden.  Unbeaufsichtigte Druckvorgänge sind in keinem
  Fall empfohlen.
* Maximale Leistungsaufnahmen aus den integrierten Stromversorgungen sind 2A
  auf dem 5V-Ausgang oder 1A auf dem 3.3V-Ausgang, wobei eine
  Gesamtleistungsaufnahme von 10W nicht überschritten werden darf.  Die
  Steckverbinder sind den entsprechenden Datenblättern zu entnehmen.
* Der X1Plus Expander darf zum Betrieb ausschließlich am Netzteil des X1
  Carbon angeschlossen werden.
* Der X1Plus Expander muss in einem Gehäuse aus nichtleitendem Material
  montiert werden und darf nicht mit leitenden Materialien in Verbindung
  kommen.
* Das Anschließen nicht zugelassener Geräte an jegliche Steckverbinder kann
  das Gerät beschädigen oder zu Einschränkungen der Funktionen beitragen und
  kann zum Erlöschen von Garantieansprüchen führen.
* Der X1Plus Expander ist nicht wasserdicht, spritzwassergeschützt oder zum
  Einsatz in feuchten oder heißen Umgebungen geeignet.  Er darf nicht auf
  nassen oder leitfähigen Oberflächen abgelegt werden, solange eine
  Netzverbindung besteht.  Ebenso darf er nicht im Inneren der Druckkammer
  und im Arbeitsbereich des Druckers platziert werden.
* Um Beschädigungen an der Leiterplatte zu vermeiden, ist Vorsicht bei der
  Handhabung geboten.  Arbeiten dürfen nur nach Unterbrechung der
  Netzverbindung vorgenommen werden.  Um das Risiko der Beschädigung durch
  elektrostatische Entladung oder mechanische Einwirkung zu vermeiden,
  sollte die Leiterplatte nur an den Außenkanten berührt werden, nicht an
  Lötstellen oder Komponenten.
* Alle eventuell verwendeten Peripheriegeräte wie etwa Zusatzmodule für den
  X1Plus Expander müssen die geltenden Sicherheitsvorschriften des Landes
  erfüllen und entsprechend gekennzeichnet sein.

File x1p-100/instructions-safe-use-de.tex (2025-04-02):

\documentclass{article}
\usepackage{fontspec}
\usepackage{multicol}
\usepackage{enumitem}
\usepackage[paperheight=7in,paperwidth=5in,margin=0.3in,heightrounded]{geometry}
\usepackage[ngerman]{babel}

\setlength{\parindent}{0in}
\setlength{\parskip}{8pt}
\setlength{\itemsep}{0in}
\setlength{\topsep}{0in}
\setlength{\tabcolsep}{0in}

\setmainfont{Futura Std}

\begin{document}

% \fontspec{Futura Std}
% \fontsize{9}{13.9}
% \selectfont
\fontsize{10}{10}\selectfont

\textbf{Thank you for buying X1Plus Expander!}  Included in this box, you will find:

\fontsize{9}{9}\selectfont
\begin{multicols}{2}
\begin{itemize}
\item{This document.}
\vspace{-3pt}
\item{1x X1P-001 wiring harness.}
\vspace{-3pt}
\item{1x X1P-002 mainboard.}
\vspace{-3pt}
\item{3x M3 x 12mm screws.}
\vspace{-3pt}
\item{1x M3 x 18mm screw.}
\vspace{-3pt}
\item{1x ping-pong ball.}
\vspace{-3pt}
\end{itemize}
\end{multicols}
\fontsize{10}{10}\selectfont

\vspace{-8pt}

First, take a moment to make sure you have it all (especially the ping-pong
ball, which Peanut, the cat, told me was very important to include), and
have a read through the Instructions for Safe Use below (or, if you prefer,
in English on the other side).  Then, scan the QR
code on the box, or go to https://accelerated.tech/expander/, to get started
installing your Expander into your printer.

\hspace*{3in}Happy printing! \\
\hspace*{3in}joshua (and Peanut)

\begin{center}
\fontsize{14}{14}\selectfont
\textbf{Sicherheitshinweise}
\end{center}

\fontsize{7}{7}\selectfont

Der X1Plus Expander ist nicht für sicherheitskritische Anwendungen vorgesehen. Verwendungen wie der Betrieb einer Druckkammerheizung im geschlossenen Regelkreis setzen unabhängige Betriebssicherheitsmaßnahmen voraus. 

Für Veränderungen am Gerät durch herstellerfremde Hardware kann keine Haftung übernommen werden. Unbeaufsichtigte Druckvorgänge sind in keinem Fall empfohlen. 

Maximale Leistungsaufnahmen aus den integrierten Stromversorgungen sind 2A auf dem 5V-Ausgang oder 1A auf dem 3.3V-Ausgang, wobei eine Gesamtleistungsaufnahme von 10W nicht überschritten werden darf. Die Steckverbinder Strom Grenzwerte sind den entsprechenden Datenblättern zu entnehmen.

Der X1Plus Expander darf zum Betrieb ausschließlich am Netzteil des X1 Carbon angeschlossen sein. 

Der X1Plus Expander muss in einem Gehäuse aus nicht leitendem Material montiert werden und darf nicht mit leitenden Materialien in Verbindung kommen.

Das Anschließen nicht zugelassener Geräte an jegliche Steckverbinder kann das Gerät beschädigen oder zu Einschränkungen der Funktionen beitragen und kann zum Erlöschen von Garantieansprüchen führen. 

Der X1Plus Expander ist nicht wasserdicht, spritzwassergeschützt oder zum Einsatz in feuchten oder heißen Umgebungen geeignet. Er darf nicht auf nassen oder leitfähigen Oberflächen abgelegt werden, solange eine Netzverbindung besteht. Ebenso darf er nicht im Inneren der Druckkammer und im Arbeitsbereich des Druckers platziert werden. 

Um Beschädigungen an der Leiterplatte zu vermeiden, ist Vorsicht bei der Handhabung geboten. Arbeiten dürfen nur nach Unterbrechung der Netzverbindung vorgenommen werden. Um das Risiko der Beschädigung durch elektrostatische Entladung oder mechanische Einwirkung zu vermeiden, sollte die Leiterplatte nur an den Außenkanten berührt werden, nicht an Lötstellen oder Komponenten. 

Alle eventuell verwendeten Peripheriegeräte wie etwa Zusatzmodule für den X1Plus Expander müssen die geltenden Sicherheitsvorschriften des Landes erfüllen und entsprechend gekennzeichnet sein.

\enddocument

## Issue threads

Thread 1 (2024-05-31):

pcb fixes

bani6809, 2024-05-31:
- [x] **rj45 connector looks potentially incorrect, needs review. pinout does not match datasheet**
- [x] C47 orientation can be improved - rotate 90'
- [x] USB esd protcetion are potentially stubs
- [x] GND via near Net-U3-SW pad 1 is useless
- [x] increase margin near net-u3-sw-1 pad
- [x] concern that the 5v above the camo_dp may have induced currents from the switcher
- [x] xtal for lan9514 on the back, may have excess parasitic capacitance and xtalk. keep lengths short and avoid layer changes
- [x] adbus0, adbus1 acute angles
- [x] potentially redefine camo_dp and ftdi_dp so the differential pairs do not have to cross (choice of ports is arbitrary)
- [x] use internal polygon plane for vcore on ftdi_dp
- [x] vdd18core can potentially use polygon plane in 2nd layer to clear up top layer
- [x] save a whole $1.43 on the order by putting silkscreen "JLCJLCJLCJLC" under one of the gpio headers
- [x] add more vias for noise suppression. there are some but could be more
- [x] consider adding diodes for reverse polarity protection, add idiot proofing to the board. users will see 5v and 3v and try to feed it power

bani6809, 2024-05-31:
i verified the easyeda footprint matches the datasheet for the following rj45 connectors:

https://www.lcsc.com/product-detail/Ethernet-Connectors-Modular-Connectors-RJ45-RJ11_HANRUN-Zhongshan-HanRun-Elec-HR911103A_C375844.html

https://www.lcsc.com/product-detail/Ethernet-Connectors-Modular-Connectors-RJ45-RJ11_HCTL-HC911102A-904-A_C5341216.html

https://www.lcsc.com/product-detail/Ethernet-Connectors-Modular-Connectors-RJ45-RJ11_HCTL-HC913129AE-907-A_C5341218.html

jwise, 2024-05-31:
LAN1 replaced with C375844, 7b0b5fa

jwise, 2024-05-31:
C41 rotated, c550f1c

jwise, 2024-05-31:
Agree that USB ESD are stubs but I am not super duper worried in this case.  The longest route is 9.5mm; with a propagation velocity of 60%, that's 52ps.  On a 480MHz signal, that's 2083ps, so we are well well well well *well* below lambda/4.  I will waive that one.

Useless via removed.

Increased clearance on net between U3 and L1 to 0.3mm.

Modified 5V routing to go away from `CAMO_DN`.  `CAMO_DP` still has a relatively tight ground route around there but hopefully the return current should go on the inner planes rather than through there.  23119ad

jwise, 2024-05-31:
ADBUS0 and ADBUS1 routing repaired in e314819.

jwise, 2024-05-31:
Vcore on FTDI moved to In2.Cu in 2591d1b.

jwise, 2024-05-31:
Vdd18core moved to inner copper layer.  But to be honest all of that routing is a clusterfuck that I am not proud of.  The less said about it the better.  If I were to redo it I would have kept the 0402s and I would move FB1 north so that I could more easily route the differential USB traces around it.  cb720ee

Waiving the camo and ftdi cross.  Probably a good idea but more effort now than it is worth to reroute.

My dignity is worth $1.43.  Waived.

Stapled ground planes with 5mm via grid where design rules permitted.  9cd169a

Waiving reverse polarity protection / idiotproofing.  Fuck around and find out.

I agree with the xtal thing, the layout guidelines did say to place it far away from other things but I'm not sure why I put it on that side.  I'll get to that one tomorrow.

bani6809, 2024-05-31:
concern that the single 5v via + trace may not provide enough current.
extend 5v plane polygon to the GPIO 5V pins and bottom layer traces can probably be removed.

bani6809, 2024-05-31:
i dont care if users blow up the board but we should think about ways they could short out the expander board or feed power back into the AP and blow it out. basically, direct paths from any of the external connectors back to the AP.

uart is unprotected and that goes right into the rockchip does it not.

jwise, 2024-06-01:
UART protection in b5f2906b44e1ea9977de329c13b2cd18d99430af

gpio 5v fattened in 2402ba38cf76c6adddf3df264edbf50903e8b924

jwise, 2024-06-01:
xtal moved up to the top in d1a6997

Closed 2024-06-01.

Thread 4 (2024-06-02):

C47 is wrong and shall asplode

bani6809, 2024-06-02:
C47 is 10V and it is on a 24V rail

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

bani6809, 2024-06-02:
dupe of #5

Closed 2024-06-02.

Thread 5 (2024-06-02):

C47 voltage rating is insufficient in A01

jwise, 2024-06-02:
C47 is a 10V cap in A01, but C47 decouples a 24V rail.

*Impact*: C47 may fail in all operating conditions.

*A01 workaround*: Rework with Taiyo Yuden GMK325BJ226MM (LCSC #C778721) as package-compatible alternative.  Mark as Rwk.1.

*A02 fix*: Increase package footprint to larger electrolytic, specify 100uF 35V cap.  (26.4V or higher: 24V + 10%)

Closed 2024-06-26.

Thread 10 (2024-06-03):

X1P-001-A02: flip connectors on MH-1.25-4R

jwise, 2024-06-03:

Closed 2024-06-19.

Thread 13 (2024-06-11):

USB ports interfere with each other

jwise, 2024-06-11:

bani6809, 2024-06-13:
USB official spec defines the allowed type A plug overmold dimensions:

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

16mm x 8mm would seem to be a good minimum

jwise, 2024-06-13:
I am thinking that a vertical USB socket would be a good approach to avoid having to change the dimensions of the board.

bani6809, 2024-06-13:
something like this one then

https://www.lcsc.com/product-detail/USB-Connectors_SHOU-HAN-AF-14-0-CC-T_C456020.html

jwise, 2024-06-13:
yeah, that looks like a good option

bani6809, 2024-06-14:
this may be easier to route:
https://www.lcsc.com/product-detail/USB-Connectors_XUNPU-USB-226-BRW_C720524.html

jwise, 2024-06-14:
hmm though with the EEPROM we can configure the LAN9514 to swap P and N for us, but I will look at that one too

Closed 2024-06-26.

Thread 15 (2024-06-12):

TEST2 and TEST3 are wrong, they are reversed

bani6809, 2024-06-12:
TEST2 and TEST3 are wrong, they are reversed.

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

reference design:

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

jwise, 2024-06-13:
schematic change in e76d6e2

Closed 2024-06-26.

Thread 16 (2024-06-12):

A01 bringup

jwise, 2024-06-12:
Status:
* 24V -> 5V switcher seems to work correctly -- datasheet efficiency is 85%, and we're hitting that
* 5V -> 3v3 linear reg works fine
* known issue on the LAN9514: TEST2 and TEST3 are swapped.  symptom is that the 1v8 reg does not come up.  TEST2 should be connected to ground, TEST3 to 3v3.  current known fix for that is to depop the LAN9514, cut the traces, and repop the LAN9514, then wire out the sides.  if I do this, then the LAN9514's 1v8 regs start up.
* known issue on the LAN9514: VBUS_DET is open, should be connected to 3v3.  wire out the side.
* unknown issue on the LAN9514: even with VBUS_DET asserted, I do not get a pullup on D+ (tested on serial number 1002) and it does not enumerate.  **this is the big issue that I need to debug before going to rev B.**
* the FTDI circuit appears to work, at least, when I wire it directly to a USB connector, skipping the LAN9514.
* harness signal integrity issue: when I loosely airwire the harness to a USB connector, the FTDI does not enumerate.  will try twisting the USB pins together.

board status:
* serial number 1001: LAN9514 is blown up.  there was a 'pop!' while I was depopping it.  I wondered if there was some moisture in the solder.  the 'pop!' was, in fact, that I had not powered it down before I hit it with hot air.  awkward.  I will use that board to test the polyfuses at least and for mechanical tests.
* serial number 1002: did rework on LAN9514
* serial number 1003 - 1010: in box, untouched

next steps:
* consider feasibility of going in with a drill to cut traces instead of depopping QFN64 on S/N 1003 (use 1001 for practice)
* scope EECLK to see if part is alive at all on 1002
* check solder with microscope on 1002

Closed 2024-10-14.

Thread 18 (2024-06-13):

Add power LED

bani6809, 2024-06-13:
Aka idiot light

bani6809, 2024-06-18:
fixed by #20

Closed 2024-06-18.

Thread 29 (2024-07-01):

replace usb polyfuse with current limiter

bani6809, 2024-07-01:
better to add current limiting devices to protect the usb ports, rather than relying on the polyfuse.

Closed 2024-10-14.

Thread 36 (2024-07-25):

formalize+document expander board eeprom

bani6809, 2024-07-25:
formalize+document expander board eeprom

e.g. d6-clk/d7-dat with i2c eeprom of minimum X byte capacity, and the following structured content.

zombu2, 2025-01-20:
just out of curiosity what does this eeprom do ?

jwise, 2025-01-21:
I need to document both onboard and module EEPROMs, but they are:
* for mainboard: lan9514 config data
* model number identifier
* serial number identifier
* hash and signature of model + serial number to verify authentic modules (unsigned EEPROMs will work perfectly fine without, they will just display a warning on boot in official X1Plus firmware that sad-face please buy the real thing to support the project... it's open source so patch it out if you must)

zombu2, 2025-01-21:
oh aright well thank you for the info i was just curious

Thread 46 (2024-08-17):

x1p-005 swap ld4 / ld5

bani6809, 2024-08-17:
ftdi powerup defaults to ld4 DTR high, which drives beeper by default.

swap ld4 / ld5, so that ld5 is beeper and ld4 drives eeprom

bani6809, 2024-09-05:
this will be fixed a different way.

Closed 2024-09-05.

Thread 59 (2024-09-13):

X1P-002: BOM reduction

jwise, 2024-09-13:
remove 0R straps, homogenize parts.  blocks #58

jwise, 2024-09-19:
done (almost) in x1p-002-c01; found one extra 0R 0402 and enqueued for X1P-002-C02

Closed 2024-09-19.

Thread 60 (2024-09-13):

X1P-002: 5V buck to 3A

jwise, 2024-09-13:
blocks #58

jwise, 2024-09-13:
Selected Silergy SY8205FCC (LCSC #C111875) -- good efficiency, 500 kHz.  Built in OCP is only to save the regulator so needs input OCP/polyfuse (check DCR!) and also needs active OCP on user-accessible 5V and 3V3.

Inductor requirement is for L >= 6.6 uH, Isat > 3.5A (for 3A input).  Datasheet suggests DCR < 10 mOhm, but that is hard to come by.  CYA1040-6.8UH (LCSC C6364676, second source C7502775) seems good, DCR = 22 mOhm, Isat = 10A.  Also acceptable is current package 6.8 uH equivalent, CYA0630-6.8UH (LCSC 5189749) at 50 mOhm DCR, Idc = 4A, Isat = 6.3A.  Inductance on both is +/- 20% but regulator d/s indicates that "SY8205 is quite tolerant of different ripple current amplitude".

Same reg can be reused for 5V -> 3.3V.

jwise, 2024-09-13:
Reg D/S indicates 47 uF X5R on output and 10 uF X5R on input.

jwise, 2024-09-19:
layout complete, released in x1p-002-c01

Closed 2024-09-19.

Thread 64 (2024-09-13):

X1P-002: rework with FT4232 and validate, modify BOM for FT4232

jwise, 2024-09-13:
blocks #58

jwise, 2024-09-16:
FT2232 delenda est

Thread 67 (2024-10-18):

X1P-001: sighting: 24V wires fatigued at X1P-002 end

jwise, 2024-10-18:
May be worth a hot melt or other strain relief at the connector-wire interface?

WolfwithSword, 2024-10-18:
For reference:
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

jwise, 2024-12-04:
To be fixed in X1P-001-A03 with silastic glue.

jwise, 2024-12-21:
fixed in a03

Closed 2024-12-21.

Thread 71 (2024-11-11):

X1P-001: get quotes for cable mfg

jwise, 2024-11-11:
Reached out to Nangudi and Oseisy.

jwise, 2024-11-21:
Have samples pending from Oseisy.  Nangudi came with a quote, I need to figure out whether they have any thinner cable as an option.

jwise, 2024-12-21:
placed order with Oseisy

Closed 2024-12-21.

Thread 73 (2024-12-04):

X1P-002: power supply stability changes

jwise, 2024-12-04:
- [ ] Change feedforward cap C49 to 100 pF
- [ ] Add 22 uF of X7R capacitance on output of 5V buck (GMK325BJ226MM-P)
- [ ] Change inductor BOM line item to 6.8 uH

jwise, 2024-12-04:
C49 swapped to 100 pF.

C8 / C47 / C50 swapped from CL10A226MQ8NRN to CL32B226KOJNNNE, adding 30 uF of effective capacitance.

Inductor BOM has been fixed.

Closed 2024-12-04.

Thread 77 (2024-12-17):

Issue Running Wire Harness yaml file through WireViz

Josh-B-1209, 2024-12-17:
Installed a fresh copy of python 3.13, pip and graphviz before trying to run the yaml file through wireviz, then got the error "dll_mh1_25_12y.png was not found in any of the following locations:
C:\Users\joshb".

Closed 2024-12-17.

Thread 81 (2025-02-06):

x1p-002: consider moving traces away from mounting holes

jwise, 2025-02-06:
there is enough vibration that this is something to be considered for long term reliability; the recommended case probably will be OK because it holds the board in compression against plastic, but if someone decided to loosely hold it on a screw or something, this would obviously be bad

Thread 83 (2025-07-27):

link to sHORTY's X1P-005 case

jwise, 2025-07-27:
https://makerworld.com/en/models/1643982-housing-x1p-expander-led-addon-module#profileId-1737377

This is great!  Link to it from the getting started guide.

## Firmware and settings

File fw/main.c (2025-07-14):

#include <stdlib.h>
#include <stdio.h>
#include <string.h>

#include "bsp/board_api.h"
#include "tusb.h"

#include "usb_descriptors.h"

#include "hardware/watchdog.h"
#include "hardware/pio.h"
#include "hardware/structs/pads_bank0.h"
#include "hardware/structs/pads_qspi.h"
#include "hardware/structs/io_qspi.h"
#include "ws2812.pio.h"
#include "pio_i2c.h"

extern int bb_i2c_read(int scl, int sda, uint8_t addr, uint8_t *buf, size_t len);
extern int bb_i2c_write(int scl, int sda, uint8_t addr, uint8_t *buf, size_t len);
extern int bb_i2c_write_read(int scl, int sda, uint8_t addr, uint8_t *buf, size_t wrlen, size_t rdlen);

void put_ws2812(int pin, uint8_t *buf, int pixels) {
	PIO pio = pio0;
	int sm = 0;
	pio_clear_instruction_memory(pio);
	uint offset = pio_add_program(pio, &ws2812_program);

	ws2812_program_init(pio, sm, offset, pin, 800000 /* freq */, 0 /* is_rgbw */);

	for (int i = 0; i < pixels; i++) {
		uint32_t pxl = 0;
		pxl = (pxl | *(buf++)) << 8;
		pxl = (pxl | *(buf++)) << 8;
		pxl = (pxl | *(buf++)) << 8;
		pio_sm_put_blocking(pio, sm, pxl);
	}
	uint32_t stall_mask = 1 << (PIO_FDEBUG_TXSTALL_LSB + sm);
	pio->fdebug = stall_mask;
	while ((pio->fdebug & stall_mask) == 0)
		;
	pio_sm_set_enabled(pio, sm, false);
}


uint8_t xbuf[512];

void do_read(void *buf, int len) {
	while (len) {
		while (tud_vendor_available() == 0) {
			/* timeout ... */
			/* check for disconnect ... */
			tud_task();
		}
		int n = tud_vendor_read(buf, len);
		buf += n;
		len -= n;
	}	
}

void do_i2c() {
	uint8_t sda, scl;
	do_read(&scl, 1);
	do_read(&sda, 1);
	
	printf("enter i2c subcmd, sda %d, scl %d\n", sda, scl);
	while (1) {
		uint8_t cmd;
		do_read(&cmd, 1);
		
		switch (cmd) {
		case 0x00:
			printf("done\n");
			goto alldone;
		case 0x01: /* read */ {
			uint8_t addr;
			uint8_t bytes;
			
			do_read(&addr, 1);
			do_read(&bytes, 1);
			
			printf("read %d bytes from adr %02x\n", bytes, addr);
			
			int result = bb_i2c_read(scl, sda, addr, xbuf, bytes);
			printf("  -> %d\n", result);
			tud_vendor_write(&result, 1);
			if (bytes)
				tud_vendor_write(xbuf, bytes);
			break;
		}
		case 0x02: /* write */ {
			uint8_t addr;
			uint8_t bytes;
			
			do_read(&addr, 1);
			do_read(&bytes, 1);
			do_read(xbuf, bytes);
			
			printf("write %d bytes to adr %02x\n", bytes, addr);
			
			int result = bb_i2c_write(scl, sda, addr, xbuf, bytes);
			printf("  -> %d\n", result);
			tud_vendor_write(&result, 1);
			break;
		}
		case 0x03: /* write, then read */ {
			uint8_t addr;
			uint8_t wrbytes;
			uint8_t rdbytes;
			
			do_read(&addr, 1);
			do_read(&wrbytes, 1);
			do_read(&rdbytes, 1);
			do_read(xbuf, wrbytes);
			
			printf("write/read %d/%d bytes to adr %02x\n", wrbytes, rdbytes, addr);
			
			int result = bb_i2c_write_read(scl, sda, addr, xbuf, wrbytes, rdbytes);
			printf("  -> %d\n", result);
			tud_vendor_write(&result, 1);
			if (rdbytes)
				tud_vendor_write(xbuf, rdbytes);
			break;
		}

		}
	}
alldone:
	tud_vendor_write_flush();
}

int main(void)
{
	watchdog_enable(1000, 0); /* reboot after 1s of being disconnected from USB, or not being in a state where we could process a command */

	board_init();
	tud_init(BOARD_TUD_RHPORT);

	if (board_init_after_tusb) {
		board_init_after_tusb();
	}

	while (1) {
		tud_task(); // tinyusb device task
		if (tud_mounted()) {
			watchdog_update();
		}
		
		/* handle the vendor RX FIFO */
		if (tud_vendor_available() >= 1) {
			uint8_t cmd;
			do_read(&cmd, 1);
			
			switch (cmd) {
			case 0x01: { /* ws2812 */
				uint16_t len;
				uint8_t pin;
				do_read(&len, 2);
				do_read(&pin, 1);
				printf("vendor: got ws2812 command for %d bytes on pin %d\n", len, pin);
				do_read(xbuf, len);
				printf("vendor: got data\n");
				put_ws2812(pin, xbuf, len / 3);
				break;
			}
			case 0x02: { /* configure gpio */
				uint8_t pin;
				uint8_t cfg;
				do_read(&pin, 1);
				do_read(&cfg, 1);
				uint8_t padcfg = PADS_BANK0_GPIO0_IE_BITS | PADS_BANK0_GPIO0_DRIVE_BITS | ((cfg & 1) ? PADS_BANK0_GPIO0_PUE_BITS : 0) | ((cfg & 2) ? PADS_BANK0_GPIO0_PDE_BITS : 0);
				if (pin < 32) {
					pads_bank0_hw->io[pin] = padcfg;
					io_bank0_hw->io[pin].ctrl = GPIO_FUNC_SIO;
					if (cfg & 4) {
						sio_hw->gpio_oe_set = 1 << pin;
					} else {
						sio_hw->gpio_oe_clr = 1 << pin;
					}
					if (cfg & 8) {
						sio_hw->gpio_set = 1 << pin;
					} else {
						sio_hw->gpio_clr = 1 << pin;
					}
				} else {
					pads_qspi_hw->io[pin - 32] = padcfg;
					io_qspi_hw->io[pin - 32].ctrl = GPIO_FUNC1_SIO;
					if (cfg & 4) {
						sio_hw->gpio_hi_oe_set = 1 << (pin - 32);
					} else {
						sio_hw->gpio_hi_oe_clr = 1 << (pin - 32);
					}
					if (cfg & 8) {
						sio_hw->gpio_hi_set = 1 << (pin - 32);
					} else {
						sio_hw->gpio_hi_clr = 1 << (pin - 32);
					}
				}
				gpio_put(pin, (cfg & 8) == 8);
				gpio_set_dir(pin, (cfg & 4) == 4);
				printf("vendor: set pin %d gpio %02x\n", pin, cfg);
				break;
			}
			case 0x03: { /* read GPIO */
				uint8_t pin;
				do_read(&pin, 1);
				uint8_t data;
				if (pin < 32) {
					data = (sio_hw->gpio_in & (1 << pin)) != 0;
				} else {
					data = (sio_hw->gpio_hi_in & (1 << (pin - 32))) != 0;
				}
				printf("vendor: pin %d is value %d\n", pin, data);
				tud_vendor_write(&data, 1);
				tud_vendor_write_flush();
				break;
			}
			case 0x04: { /* do I2C subcommand */
				do_i2c();
				break;
			}
			case 0x05: { /* read all GPIOs */
				uint32_t data[2];
				data[0] = sio_hw->gpio_in;
				data[1] = sio_hw->gpio_hi_in;
				tud_vendor_write(data, 8);
				tud_vendor_write_flush();
				break;
			}
			default:
				printf("vendor: unknown command %02x\n", cmd);
			}
		}
	}
}

void tud_mount_cb(void) {
	printf("USB connected\n");
}

void tud_umount_cb(void) {
	printf("USB disconnected\n");
}

void tud_suspend_cb(bool remote_wakeup_en) {
}

void tud_resume_cb(void) {
}

/* we do not use vendor_rx_cb / vendor_tx_cb since we handle these synchronously in the main processing loop */
#if 0
void tud_vendor_rx_cb(uint8_t itf, uint8_t const* buf, uint16_t bufsz) {
	printf("vendor: got %d bytes on itf %d\n", bufsz, itf);
}

void tud_vendor_tx_cb(uint8_t itf, uint32_t sent_bytes) {
	printf("vendor: did tx %ld bytes on itf %d\n", sent_bytes, itf);
}
#endif

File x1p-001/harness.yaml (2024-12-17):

metadata:
  title: X1Plus Expander Wiring Harness
  pn: X1P-001
  
  authors:
    created:
      name: J. Wise
      date: 2024-06-19
  
  revisions:
    A01:
      name: J. Wise
      date: 2024-05-13
      changelog: Initial revision.
    
    A02:
      name: J. Wise
      date: 2024-06-19
      changelog: Added twisted pairs for USB.  Added heat shrink.  Fixed order of CAM_USB pins.
    
    A03:
      name: J. Wise
      date: 2024-11-14
      changelog: Switched from individual cables to ribbon cable.

    A04:
      name: J. Wise
      date: 2024-12-16
      changelog: Added heat shrink labels.  Shortened power components of harness.
  
  template:
    name: din-6771
    sheetsize: A3

templates:
  - &mh125t
    type: MH1.25-T
    qty_multiplier: pincount
    supplier: LCSC
    spn: C20613846
  - &glue
    type: Glue on connector
  - &mh125rt
    additional_components:
      - type: MH1.25-RT
        qty_multiplier: pincount
        supplier: LCSC
        spn: C20613847

connectors:
  EXT:
    type: DLL MH1.25-12Y
    supplier: LCSC
    spn: C20613692
    pins: [ 12, 11, 10, 9, 8, 7, 6, 5, 4, 3, 2, 1 ]
    pinlabels: [ CAM5V, CAMD-, CAMD+, CAMGND, MBD-, MBD+, UART3V3, UARTRX, UARTTX, UARTGND, PSU24V, PSUGND ]
    additional_components:
      - <<: *glue
      - <<: *mh125t
      - type: "Add 16mm heat shrink label on wires with X1Plus logo"
    image:
      src: dll_mh1_25_12y.png
      width: 200
  MB_USB:
    type: DLL MH1.25-4Y
    supplier: LCSC
    spn: C20613684
    pinlabels: [ MB5V, MBD-, MBD+, MBGND ]
    image:
      src: dll_mh1_25_4y.png
      width: 200
    additional_components:
      - <<: *glue
      - <<: *mh125t
      - type: "Add heat shrink label on wire: 'CAM'"
  MB_UART:
    type: DLL MH1.25-4Y
    supplier: LCSC
    spn: C20613684
    pinlabels: [ UART3V3, UARTRX, UARTTX, UARTGND ]
    image:
      src: dll_mh1_25_4y.png
      width: 200
    additional_components:
      - <<: *glue
      - <<: *mh125t
      - type: "Add heat shrink label on wire: 'UART'"
  CAM_USB:
    type: DLL MH1.25-4R
    supplier: LCSC
    spn: C20613669
    pinlabels: [ CAMGND, CAMD+, CAMD-, CAM5V ]
    image:
      src: dll_mh1_25_4r.png
      width: 200
    additional_components:
      - <<: *glue
      - type: MH1.25-RT
        qty_multiplier: pincount
        supplier: LCSC
        spn: C20613847
  MB_PSU:
    type: HC-PHB-2*3-Y
    supplier: LCSC
    spn: C2979578
    pinlabels: [ 24V_0, 24V_1, 24V_2, GND_0, GND_1, GND_2 ]
    image:
      src: hc_phb_2_3_y.png
      width: 200
    additional_components:
      - <<: *glue
      - type: HC-PHB-T
        qty_multiplier: pincount
        supplier: LCSC
        spn: C2979596
  PSU_IN:
    type: HC-PHB-2*3EY-05
    supplier: LCSC
    spn: C18548022
    image:
      src: hc_phb_2_3_ey.png
      width: 200
    pinlabels: [ 24V_0, 24V_1, 24V_2, GND_0, GND_1, GND_2 ]
    additional_components:
      - <<: *glue
      - type: HC-PHB-PT-05
        qty_multiplier: pincount
        supplier: LCSC
        spn: C18548040

# panel to MB:
#   20mm slack
#   40mm Y
#   120mm X to edge
#   85mm to cam / UART connector = 270mm
#   170mm to power connector = 350mm

cables:
  W_RIBBON:
    wirecount: 10
    colors: [ RD, GY, GY, GY, GY, GY, GY, GY, GY, GY ]
    length: 205 mm
    gauge: 28 AWG
    type: 1.0mm 28AWG stranded ribbon cable (3M 3625/10 or similar)
  W_EXT_PSU:
    category: bundle
    wirecount: 2
    length: 273 mm
    gauge: 26 AWG
    colors: [ RD, BK ]
    additional_components:
      - type: Heat shrink sleeve, red
        qty_multiplier: length
        unit: mm
  W_MB_PSU:
    category: bundle
    wirecount: 6
    length: 25 mm
    gauge: 24 AWG
    colors: [ RD, RD, RD, BK, BK, BK ]

connections:
  -
    - EXT: [12, 11, 10, 9]
    - W_RIBBON: [1-4]
    - CAM_USB: [4, 3, 2, 1]
  -
    - EXT: [8, 7]
    - W_RIBBON: [5-6]
    - MB_USB: [2-3]
  -
    - EXT: [6, 5, 4, 3]
    - W_RIBBON: [7-10]
    - MB_UART: [1-4]
  - 
    - EXT: [2, 1]
    - W_EXT_PSU: [1-2]
    - MB_PSU: [1, 4]
  -
    - MB_PSU: [1-6]
    - W_MB_PSU: [1-6]
    - PSU_IN: [1-6]

tweak:
  override:
    graph:
      ranksep: "4"

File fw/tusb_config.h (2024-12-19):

/*
 * The MIT License (MIT)
 *
 * Copyright (c) 2019 Ha Thach (tinyusb.org)
 *
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
 */

#ifndef _TUSB_CONFIG_H_
#define _TUSB_CONFIG_H_

#ifdef __cplusplus
 extern "C" {
#endif

//--------------------------------------------------------------------+
// Board Specific Configuration
//--------------------------------------------------------------------+

// RHPort number used for device can be defined by board.mk, default to port 0
#ifndef BOARD_TUD_RHPORT
#define BOARD_TUD_RHPORT      0
#endif

// RHPort max operational speed can defined by board.mk
#ifndef BOARD_TUD_MAX_SPEED
#define BOARD_TUD_MAX_SPEED   OPT_MODE_DEFAULT_SPEED
#endif

//--------------------------------------------------------------------
// COMMON CONFIGURATION
//--------------------------------------------------------------------

// defined by compiler flags for flexibility
#ifndef CFG_TUSB_MCU
#error CFG_TUSB_MCU must be defined
#endif

#ifndef CFG_TUSB_OS
#define CFG_TUSB_OS           OPT_OS_NONE
#endif

#ifndef CFG_TUSB_DEBUG
#define CFG_TUSB_DEBUG        0
#endif

// Enable Device stack
#define CFG_TUD_ENABLED       1

// Default is max speed that hardware controller could support with on-chip PHY
#define CFG_TUD_MAX_SPEED     BOARD_TUD_MAX_SPEED

/* USB DMA on some MCUs can only access a specific SRAM region with restriction on alignment.
 * Tinyusb use follows macros to declare transferring memory so that they can be put
 * into those specific section.
 * e.g
 * - CFG_TUSB_MEM SECTION : __attribute__ (( section(".usb_ram") ))
 * - CFG_TUSB_MEM_ALIGN   : __attribute__ ((aligned(4)))
 */
#ifndef CFG_TUSB_MEM_SECTION
#define CFG_TUSB_MEM_SECTION
#endif

#ifndef CFG_TUSB_MEM_ALIGN
#define CFG_TUSB_MEM_ALIGN          __attribute__ ((aligned(4)))
#endif

//--------------------------------------------------------------------
// DEVICE CONFIGURATION
//--------------------------------------------------------------------

#ifndef CFG_TUD_ENDPOINT0_SIZE
#define CFG_TUD_ENDPOINT0_SIZE    64
#endif

//------------- CLASS -------------//
#define CFG_TUD_HID               0
#define CFG_TUD_CDC               0
#define CFG_TUD_MSC               0
#define CFG_TUD_MIDI              0
#define CFG_TUD_VENDOR            1

#define CFG_TUD_VENDOR_EPSIZE        64
#define CFG_TUD_VENDOR_RX_BUFSIZE 512
#define CFG_TUD_VENDOR_TX_BUFSIZE 512

#ifdef __cplusplus
 }
#endif

#endif /* _TUSB_CONFIG_H_ */

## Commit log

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2024-05-29 initial full placement and routing
    [1_MAIN.kicad_sch, 3_GPIO.kicad_sch, ProProject_X1 Expander_2024-05-26_15-16-51_2024-05-26.kicad_pcb]
2024-05-30 clean up DRC and silkscreen
    [1_MAIN.kicad_sch, 3_GPIO.kicad_sch, ProProject_X1 Expander_2024-05-26_15-16-51_2024-05-26.kicad_pcb]
2024-05-30 add LCSC part tags, silkscreen
    [1_MAIN.kicad_sch, 2_LAN.kicad_sch, 3_GPIO.kicad_sch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]
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2024-05-31 replace LAN1 with C375844
    [1_MAIN.kicad_sch, 2_LAN.kicad_sch, 3_GPIO.kicad_sch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]
2024-05-31 rotate C41 for lower impedance, replace LAN1 PTH mechanicals with NPTH
    [x1-expander.kicad_pcb]
2024-05-31 5V switcher routing improvements
    [x1-expander.kicad_pcb]
2024-05-31 repair ADBUS0 and ADBUS1 routing
    [x1-expander.kicad_pcb]
2024-05-31 put FTDI VCORE on In2.Cu
    [x1-expander.kicad_pcb]
2024-05-31 move vdd18core to inner layer
    [x1-expander.kicad_pcb]
2024-05-31 staple ground planes with 5mm via grid
    [x1-expander.kicad_pcb]
2024-05-31 remove a few strange off-grid vias
    [x1-expander.kicad_pcb]
2024-06-01 add esd protection to uart
    [1_MAIN.kicad_sch, 2_LAN.kicad_sch, 3_GPIO.kicad_sch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]
2024-06-01 pcb: gpio 5v from inner layer, fatten ap dbg 3v3
    [x1-expander.kicad_pcb]
2024-06-01 move xtal to top layer
    [x1-expander.kicad_pcb]
2024-06-13 LAN: swap test2 and test3 and add straps; add pull to vbus_det; replace .1uf decaps with 0402
    [1_MAIN.kicad_sch, 2_LAN.kicad_sch, 3_GPIO.kicad_sch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]
2024-06-13 add EEPROM to schematic (#17)
    [2_LAN.kicad_sch]
2024-06-13 switch to vertical USB
    [2_LAN.kicad_sch]
2024-06-14 WIP: move passives around for U1
    [2_LAN.kicad_sch, x1-expander.kicad_pcb]
2024-06-17 route passives near LAN95xx
    [2_LAN.kicad_sch, x1-expander.kicad_pcb]
2024-06-18 place eeprom, move LAN9514 north, route ethernet
    [x1-expander.kicad_pcb]
2024-06-18 Bani6809/power led (#20)
    * add power led
    * fix crlf
    [1_MAIN.kicad_sch, 2_LAN.kicad_sch, 3_GPIO.kicad_sch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]
2024-06-18 swap USB connectors
    [2_LAN.kicad_sch, x1-expander.kicad_pcb]
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2024-06-18 escape other USB diff pairs
    [x1-expander.kicad_pcb]
2024-06-18 route leds, cleanup component silkscreen text (#21)
    [x1-expander.kicad_pcb]
2024-06-19 add power leds, ground lan1 EH (#22)
    [1_MAIN.kicad_sch, 2_LAN.kicad_sch, 3_GPIO.kicad_sch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]
2024-06-19 move x1p-002 into its own directory
    [1_MAIN.kicad_sch, 2_LAN.kicad_sch, 3_GPIO.kicad_sch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]
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2024-06-20 unroute 24v LED and route USB with one fewer layer change
    [x1-expander.kicad_pcb]
2024-06-20 clean up LED current, move LEDs, give designators some room to breathe
    [1_MAIN.kicad_sch, 2_LAN.kicad_sch, 3_GPIO.kicad_sch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]
2024-06-20 add 3dmodel for RN1 C136850
    [x1-expander.kicad_pcb]
2024-06-20 assign lcsc parts to R23, R35, R22. fix warning about unconnected RXN trace near RN1
    [1_MAIN.kicad_sch, 2_LAN.kicad_sch, 3_GPIO.kicad_sch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]
2024-06-20 reorient LED3/R23 so it do not cross differential pair
    [x1-expander.kicad_pcb]
2024-06-20 return LED3/R23 orientation. change DRC for text to 0.8mm, based on the boards we received jlcpcb obviously has no problem manufacturing it
    [x1-expander.kicad_pcb]
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2024-06-20 x1p-001: un-reverse EXT harness
    [harness.yaml]
2024-06-21 add test points; replace capacitor with big boi; route USB out of the way of vias for new capacitor
    [1_MAIN.kicad_sch, 2_LAN.kicad_sch, 3_GPIO.kicad_sch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]
2024-06-21 fix TP1 via spacing DRC violation, cleanup various silkscreen text to clear up warnings
    [x1-expander.kicad_pcb]
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2024-06-21 shove test point labels around
    [1_MAIN.kicad_sch, 2_LAN.kicad_sch, 3_GPIO.kicad_sch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]
2024-06-21 annotated everything with LCSC IDs
    [1_MAIN.kicad_sch, 2_LAN.kicad_sch, 3_GPIO.kicad_sch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]
2024-06-23 add pullup on FTDI EEDATA, swap EEPROM to 4k EEPROM
    [1_MAIN.kicad_sch, 2_LAN.kicad_sch, 3_GPIO.kicad_sch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]
2024-06-24 replace rj45 component
    [1_MAIN.kicad_sch, 2_LAN.kicad_sch, 3_GPIO.kicad_sch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]
2024-06-24 correct C3021374 footprint, route rj45
    [2_LAN.kicad_sch, x1-expander.kicad_pcb]
2024-06-25 replace F1 with proper rated part, relink RN1 with 3d model, adjust lan1 3d model z offset, move TXN & RXN meander near rj45
    [1_MAIN.kicad_sch, x1-expander.kicad_pcb]
2024-06-25 replace F1 with C5358568 - BHFUSE BSMD1206-100-30V
    [1_MAIN.kicad_sch, x1-expander.kicad_pcb]
2024-06-25 move fuse downstream of bulk USB caps; ethernet jack mechanical pins are NPTH
    [1_MAIN.kicad_sch, 2_LAN.kicad_sch, 3_GPIO.kicad_sch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]
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2024-06-29 fix annotation error
    [x1p-003.kicad_sch]
2024-07-01 x1p-003: add pogo pin step file and assign a few footprints
    [x1p-003.kicad_sch]
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2024-07-09 serialize: use class 00/00/00 for device to avoid fooling Linux into thinking this is a hub
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2024-07-13 unidirectional shifters, decouple eeprom, add jumper for sourcing 5v
    [x1p-004.kicad_pcb, x1p-004.kicad_sch]
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2024-07-17 reorient switch, update text
    [x1p-004.kicad_pcb, x1p-004.kicad_sch]
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2024-07-17 x1p-004 schem: add pull down resistors on level shifter inputs, add image for DIR input
    [x1p-004.kicad_sch]
2024-07-17 x1p-004 layout: swap 5V and GND labels, improve chomnkiness of 5V and GND traces
    [x1p-004.kicad_pcb]
2024-07-17 x1p-004 schem: fix 5V_SW to GND short
    [x1p-004.kicad_sch]
2024-07-17 x1p-004 layout: optimize some, and match schematic
    [x1p-004.kicad_pcb]
2024-07-17 x1p-004: add decap for level shifters
    [x1p-004.kicad_pcb, x1p-004.kicad_sch]
2024-07-17 x1p-004 layout: thermals are good enough for ground, do not override those
    [x1p-004.kicad_pcb]
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2024-07-29 add eeprom/switch mux, change buzzer
    [x1p-005.kicad_sch]
2024-07-29 0 drc violations \o/
    [x1p-005.kicad_pcb, x1p-005.kicad_sch]
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2024-07-30 0 drc errors \o/
    [x1p-006.kicad_pcb, x1p-006.kicad_sch]
2024-07-31 fix 3dshapes alignment
    [x1p-005.kicad_pcb]
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2024-08-28 change jack to trrs
    [x1p-006.kicad_pcb, x1p-006.kicad_sch]
2024-08-31 correct 3dmodels
    [x1p-006.kicad_pcb]
2024-09-02 change to TRS jack, change ssr to instock part, remove jumpers
    [x1p-006.kicad_pcb, x1p-006.kicad_sch]
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2024-09-07 fix reversed di/do
    [x1p-005.kicad_pcb, x1p-005.kicad_sch]
2024-09-07 x1p-005: resistors to 2.2k; remove a weird dangling trace; label beepies and clickies with their pin number (#56)
    * x1p-005: resistors to 2.2k; remove a weird dangling trace; label beepies and clickies with their pin number
    * x1p-005: rotate r3 to "correct" orientation, add second thermal spoke back to buzzer
    [x1p-005.kicad_pcb, x1p-005.kicad_sch]
2024-09-08 add clearance for LEDs from mounting holes, return symmetry to zone fills
    [x1p-005.kicad_pcb]
2024-09-13 X1P-002: schematic: redesign with larger 5V buck (#60), add 3V3 buck (#63), add OCP circuits for 3V3 and 5V (but not connected to user ports yet; #61)
    [1_MAIN.kicad_sch, 2_LAN.kicad_sch, 3_GPIO.kicad_sch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]
2024-09-13 X1P-002: schematic: add FTDI EEPROM (#62)
    [1_MAIN.kicad_sch]
2024-09-13 X1P-002: schematic: change to FT4232 (#64)
    [1_MAIN.kicad_sch]
2024-09-15 x1p-002: wire up OCP circuits to user ports (#61)
    [1_MAIN.kicad_sch, 2_LAN.kicad_sch, 3_GPIO.kicad_sch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]
2024-09-15 X1P-002: rename 1_MAIN to FTDI, in preparation for ripping out the FTDI
    [FTDI.kicad_sch, x1-expander.kicad_sch]
2024-09-15 x1p-002: WIP: rp2040 schematic
    [RP2040.kicad_sch, x1-expander.kicad_sch]
2024-09-16 X1P-002: finish connecting GPIO ports to RP2040
    [2_LAN.kicad_sch, 3_GPIO.kicad_sch, RP2040.kicad_sch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]
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2024-09-19 x1p-002: replace lytic with 4x MLCC
    [power.kicad_sch, x1-expander.kicad_pcb]
2024-09-19 x1p-002: move arrows, remove LAN1 silk, remove 0 ohm straps, add noozle and hatguy
    [2_LAN.kicad_sch, x1-expander.kicad_pcb]
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2024-09-19 X1P-002: scrub BOM and remove a stray 0402 0R
    [2_LAN.kicad_sch, 3_GPIO.kicad_sch, RP2040.kicad_sch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]
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2024-11-07 X1P-800: import correct STEP files for X1P-002-B01, rather than for A01
    [X1P-800 Clip.step, X1P-800 Lower shell.step, X1P-800 Standoff LL.step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]
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2024-12-04 X1P-002: set 5V OCP to 1.8A (fixes #74)
    [power.kicad_sch, x1-expander.kicad_pcb]
2024-12-04 X1P-002: remove LLM-generated art; make sticker space 1" x 0.5" (fixes #72)
    [x1-expander.kicad_pcb]
2024-12-04 X1P-002: clean up 5V power supply errata (fixes #73)
    [power.kicad_sch, x1-expander.kicad_pcb]
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2024-12-20 fw: add stemma i2c, fix portb7
    [fwtest.py]
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2024-12-21 tweak logo positions, tweak testpoint footprints; release x1p-002-c02
    [2_LAN.kicad_sch, 3_GPIO.kicad_sch, RP2040.kicad_sch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]
2025-01-04 x1p-002: fix silkscreen placement
    [x1-expander.kicad_pcb]
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2025-01-12 fw/test: add workaround for libusb1 on printer
    [fwtest.py, smscreset.py]
2025-01-12 add small tool to burn SMSC EEPROM from host Python
    [smsceeprom.py]
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2025-01-13 print_labels: print a known dummy label rather than a ^PH blank label, to prevent the printer from backfeeding later and eating the label
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2025-01-15 x1p-005: fix up board layout to align with x1p-004
    [x1p-004.kicad_pcb, x1p-005.kicad_pcb, x1p-005.kicad_sch]
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2025-01-16 reduce overall BOM on panels, load manufacturer and MPN in
    [x1p-004.kicad_pcb, x1p-004.kicad_sch, x1p-005.kicad_pcb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]
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2025-01-20 add King Credie recommended components, fix panel placement, fix pulldown on x1p-005, fix bridges on x1p-006
    [x1p-004.kicad_pcb, x1p-004.kicad_sch, x1p-005.kicad_pcb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]
2025-01-20 x1p-005: do not overlap a resistor with text, dur
    [x1p-005.kicad_pcb]
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2025-03-07 fwtest: add module eeprom burn tool
    [fwtest.py]
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2025-03-15 fw: refactor reset EP into its own file, turn on the WDT
    [x1p-004.kicad_pcb, x1p-005.kicad_pcb, x1p-006.kicad_pcb]
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2025-03-17 mfg: add x1p_002_c fixture mode
    [cli.py, gui.py, smsc9514.py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]
2025-03-31 expanderlib: use rp2040 reboot opcode rather than exec, for more reliable boot
    [rp2040.py]
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2025-04-20 print_mouser_label: argh the fucking Zebra produces an invalid datamatrix with inverted orientation
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2025-06-04 getting started: update firmware version, add better assembly instructions
    [X1P-800 Clip.step, X1P-800 Lower shell.step, X1P-800 Short standoff.step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]
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
